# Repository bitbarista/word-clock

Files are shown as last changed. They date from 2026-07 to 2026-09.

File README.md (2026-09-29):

# TIME INVADERS — arcade word clock

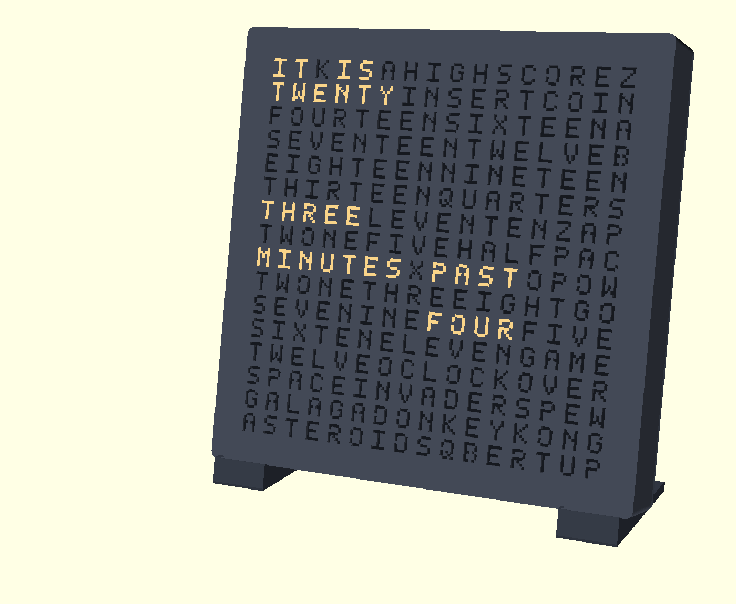
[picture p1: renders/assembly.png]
Assembled word clock on its desk feet showing IT IS TWENTY THREE MINUTES PAST FOUR


A 16×16 word clock with an 8-bit arcade heart: the time reads as words
to the exact minute (`IT IS TWENTY THREE MINUTES PAST FOUR`), but time
changes are game events — Pac-Man eats the old time, a cannon shoots
in the new one — and the filler letters hide arcade words
(INSERT COIN, GAME OVER, plus a hall of fame: SPACE INVADERS, GALAGA,
DONKEY KONG, ASTEROIDS, Q*BERT). The enclosure is deliberately subtle —
a plain dark slab that passes at a work desk, on raked feet or
wall-mounted; the arcade lives in the light, not the shell.

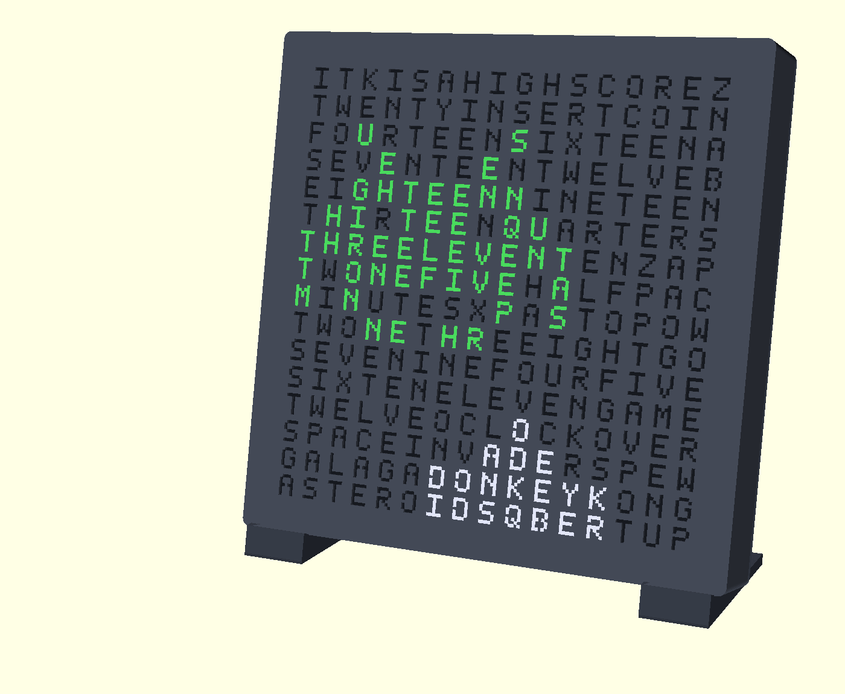
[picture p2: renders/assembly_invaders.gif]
The same clock playing the Space Invaders attract animation — an invader sprite marching over a cannon, drawn in lit letters


Every pixel is a letter: the attract-mode sprites are drawn by lighting
grid cells, like the invader marching over the cannon above.

**▶ [Try it in your browser](https://bitbarista.github.io/word-clock-demo/simulator.html)** —
live simulator running the real firmware logic: word grid, transitions,
attract mode, hidden words.

## What you need

| Item | Notes |
|---|---|
| 16×16 WS2812B flexible panel | 160×160 mm, 10 mm pitch — the common ~£12–15 one |
| Seeed XIAO ESP32S3 (or ESP32-S3 "supermini") | either fits the internal locator |
| Snap-in USB-C power socket, **4P PD pigtail** | CHT-TS023R style; 2P/data variants won't power from C-to-C cables |
| 5 V / 3 A USB-C supply | **must present 5 V** — verify with a meter before connecting the panel |
| 2× 5.1 kΩ resistors | CC1/CC2 → GND at the socket pigtail (skip if built in) |
| 1000 µF electrolytic (≥6.3 V) | across 5 V/GND at the panel pigtail |
| 330 Ω resistor | in the data line to DIN |
| Schottky diode (1N5817/19/22) | socket 5 V → ESP32 5 V pin |
| 3 mm foam sheet | cut into 14× 8×8 mm pads |
| 4× M3×**16** self-tapping screws | shell → faceplate posts (16 mm, not 8 — see [DESIGN.md](DESIGN.md)) |
| 74AHCT125 level shifter (optional) | only if 3.3 V data proves flaky |

## Print it

Sliceable files are committed — no OpenSCAD needed for a stock build:

- **[`build/desk_set.3mf`](build/desk_set.3mf)** — the desk build in
  one file: faceplate, shell, lattice, diffuser, and stand feet in
  both 12° and 15° tilt (print one pair).
- **[`build/wall_set.3mf`](build/wall_set.3mf)** — the wall build:
  keyhole hangers baked in, power socket on the bottom edge, no stand.
- [`build/`](build/) also has per-part STLs and exact STEP CAD exports
  ([`wordclock_assembly.step`](build/wordclock_assembly.step) is the
  full assembly) for other CAD tools.

Every part is a plain single-colour print: faceplate, shell, lattice
and stand in something dark; the diffuser in white or clear at 100 %
infill. Faceplate prints letters-down, shell outer-face-down,
everything else flat.

**Pick your diffuser first**: print `part="coupon"` (a four-cell
sample) plus `coupon_diffuser` strips at a few thicknesses (`t_diff` =
0.6 / 0.9 / 1.2, clear and white), try them over a lit LED, set
`t_diff` to the winner, then print the diffuser and lattice.

**Customising needs [OpenSCAD](https://openscad.org)** (free — open
`wordclock.scad`, use the Customizer): the committed files cover the
two stock configurations, everything else is a parameter + re-export —
`mount_type` (desk/wall), `power_pos` (cable entry: back or bottom),
`keyhole` (wall hangers), `tilt` (stand angle 5–25°), `t_diff`, or the
letter grid itself. `./export.sh` regenerates STLs + 3MF sets,
`./export_step.sh` the STEP files.

## Wire it

Four connections plus the supply handshake — see the schematic for the
full picture:

- Socket **V+/V− → panel 5 V/GND direct** (panel current never touches
  the ESP32), with the **1000 µF cap** across 5 V/GND at the panel
  pigtail.
- Socket 5 V **→ D1 (Schottky, cathode toward ESP32) → ESP32 5 V pin**;
  grounds common.
- ESP32 **GPIO4 → 330 Ω → panel DIN**.
- **CC1/CC2 → 5.1 kΩ → GND** (one each) at the socket pigtail, unless
  the socket has them built in.

Firmware enforces a per-frame power cap
(`FastLED.setMaxPowerInVoltsAndMilliamps(5, 2500)`) so no animation
can exceed the supply — don't remove it. Power-safety details and why
each part is there: [DESIGN.md](DESIGN.md).

<details>
<summary>Full circuit schematic (ASCII)</summary>

```
+=========================================================================+
|                   TIME INVADERS -- Circuit Schematic                    |
+=========================================================================+

POWER

  USB-C Power Pod (snap-in, 4P fast-charge/PD pigtail)
  +-------------+
  |  V+         |----------------------------------------------- 5V RAIL
  |  V-         |----------------------------------------------- GND RAIL
  |  CC1        |--[ R1 5.1k ]--+
  |  CC2        |--[ R2 5.1k ]--+-------------------------------- GND RAIL
  +-------------+

  R1/R2 request 5V/3A from the supply. Omit them if the socket
  already has CC resistors built in (only V+/V- emerge in that case).

  ESP32-S3 SuperMini
  5V RAIL  --[ D1 ]------------------------------------------------ 5V pin
  GND RAIL ------------------------------------------------------ GND pin

  D1: pod 5V -> ESP32 5V pin, cathode (banded end) toward the ESP32.
  Reinstates the isolation the XIAO's own USB port likely lacks (see
  note below) -- without it, don't power from the pod and a flashing
  cable at once.

  On hand: 1N5817 -- genuine Schottky (same 1N581x family as the
  1N5822/1N5819 the BOM recommends), 20V/1A, VF ~0.2-0.45V. Only
  difference from the BOM pick is current rating (1A vs 3A), which is
  fine here: D1 only carries the ESP32's own draw, not the panel
  (panel is fed V+/V- direct, bypassing D1) -- 1A comfortably covers
  the XIAO even during WiFi TX current spikes.

  ESP32-S3's OWN programming USB-C (internal cradle -- the only
  proven way to flash; web OTA is unproven, see Assemble it)

    USB-C connector
     VBUS ----------[ onboard Schottky ]---------------------- 5V RAIL
     GND  ------------------------------------------------------ GND RAIL

  This diode blocks GND RAIL -> VBUS backfeed, but NOT the reverse:
  if a laptop's VBUS sits above the pod's output, the laptop can end
  up sourcing panel current through this small onboard diode. The
  firmware's USB power guard detects a host on this port (via USB
  enumeration) and automatically clamps LED current to a safe budget
  while it's connected -- no extra wiring, but don't rely on the
  diode alone.

LED PANEL (16x16 WS2812B, 160x160mm, 256 LEDs)

  5V RAIL  --+----------------------------------------------------- Panel VCC
             |
         [ C1 1000uF ]
             |
  GND RAIL --+----------------------------------------------------- Panel GND

  ESP32-S3                                            Panel
  GPIO4 -----[ R3 330R ]----------------------------- DIN

  GPIO4 is a build flag (LED_PIN in platformio.ini) -- change there,
  not here, if your wiring differs. Optional: insert a 74AHCT125
  level shifter between R3 and DIN if 3.3V data proves unreliable
  driving the panel from 5V.

All GND labels share a common ground.
All 5V RAIL labels are the same net: fed primarily by the power pod
(V+/V- direct, no diode), and -- only while a host is enumerated on
the programming port -- additionally by that port's VBUS through the
onboard diode (current-limited in firmware when this happens).
```

</details>

## Assemble it

1. **Flash the ESP32 first** — over USB on the bench. The firmware has
   a web OTA endpoint, but it is **unproven**: its only real-world use
   sent a build that turned out to be broken, so OTA itself was never
   confirmed working. There's no external port on the finished clock,
   so recovering from a bad update means opening the case to reach the
   ESP32's USB-C. Until OTA is proven on a bench unit, plan to update
   over USB with the case open.
2. Faceplate letters-down on the desk → diffuser sheet into the
   opening → lattice on top of it → panel, **wire-exit edge toward the
   bottom** (shortest runs to the ESP32 and socket; firmware's mapping
   settings absorb whatever rotation this gives).
3. Foam pads on the 14 grid points; wiring lies in the open cavity
   between them.
4. Shell — with ESP32 (USB-C connector toward the locator's open end),
   power socket, and wiring attached — then four M3×16 screws.

First power-on: run a test pattern, set the panel mapping
(rotate/flip/serpentine) in the web UI, then leave it on attract mode
for a few hours and check nothing runs more than warm (the vent sizing
is calculated but not yet soak-validated — see [DESIGN.md](DESIGN.md)).

## Firmware

Lives on the [`firmware` branch](../../tree/firmware) (PlatformIO,
ESP32-S3). NTP + web UI — animation pick/interval, colours, brightness
schedule, timezone, panel mapping — with transition animations
(Pac-Man eat, cannon shoot-up, Tetris drop, invader zap), attract mode and
hidden-word easter eggs. Works fully offline too: it hosts its own
hotspot and can take the time from your phone with one tap
([DESIGN.md](DESIGN.md) has the details).

## The letter grid

```
IT K IS A HIGHSCORE Z         rows 0-8: minute words
TWENTY INSERTCOIN             rows 9-12: hour words + OCLOCK
FOURTEEN SIXTEEN A            rows 13-15: arcade hall of fame
SEVENTEEN TWELVE B
EIGHTEEN NINETEEN             hidden arcade words:
THIRTEEN QUARTER S            HIGH SCORE, INSERT COIN,
THREELEVEN TEN ZAP            ZAP/PAC/POW (stacked), GO,
TWONE FIVE HALF PAC           GAME/OVER (stacked),
MINUTES X PASTO POW           SPACE INVADERS, PEW, GALAGA,
TWONE THREEIGHT GO            DONKEY KONG, ASTEROIDS, QBERT, UP
SEVENINE FOUR FIVE
SIX TEN ELEVEN GAME
TWELVE OCLOCK OVER
SPACEINVADERS PEW
GALAGA DONKEYKONG
ASTEROIDS QBERT UP
```

Words share letters to fit per-minute wording into 16×16 (TWONE =
TWO+ONE, PASTO = PAST+TO, …) — the full construction is in
[DESIGN.md](DESIGN.md).

## More detail

- **[DESIGN.md](DESIGN.md)** — design notes and rationale: power
  budget, enclosure stack, ventilation, diffuser experiment, offline
  timekeeping, full BOM component notes.
- **[DEVLOG.md](DEVLOG.md)** — the engineering history: every bug,
  root cause, fix, and how each was verified.
- **[Concept comparison](https://bitbarista.github.io/word-clock-demo/wordclock-concepts.html)** —
  the enclosure concepts considered (arcade cabinet vs. subtle wedge);
  both demo pages are archived in [`docs/`](docs/) and mirrored to
  [word-clock-demo](https://github.com/bitbarista/word-clock-demo) for
  GitHub Pages hosting.

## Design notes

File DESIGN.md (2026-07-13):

# Design notes — TIME INVADERS word clock

[README.md](README.md) is the build guide; this file holds the design
rationale and current-state detail behind it. [DEVLOG.md](DEVLOG.md)
has the engineering history of how it all got this way.

## Project status

**v0.1.6 — model validated (manifold + collision-checked).**
Faceplate, shell, and stand have all been printed and iterated on
previous revisions, but v0.1.6 changed the depth budget, the
bezel/pocket wall, the power socket mount, and (to actually fit the
thicker slab) the stand's own wedge geometry (see [DEVLOG.md](DEVLOG.md)) —
**reprint the faceplate, shell, and stand** before assembling against
this revision; the old stand's slot was cut for the pre-v0.1.6 slab
thickness and won't fit. Firmware exists on the `firmware` branch (fw
v0.3.0, not yet merged to `main`), not started from scratch.

(The solid `stand` wedge and its `stand_sheet` variant discussed in
the devlog were superseded by `stand_feet`/`stand_lowtail`; the
groove/tilt/vent-relief profile work described there carried over
into both current stands.)

## Component notes (full BOM detail)

- **Seeed XIAO ESP32S3 or a generic ESP32-S3 "supermini"** — WiFi NTP
  + web UI + animations. Originally XIAO-only after none of three
  boards (two supermini vendors + the XIAO) fit an earlier snug
  cradle — since resolved (v0.1.4): the cradle is now a universal
  locator (`brd_w`/`brd_l`) sized to fit either, single end-stop only
  (see ESP32 access below).
- **Snap-in USB-C power socket, 4P PD pigtail** — CHT-TS023R style,
  5 A; 2P variant won't work with C-to-C cables. Mounts directly into
  the shell now, no separate pod part or screws (see Power budget &
  protection below).
- **1000 µF electrolytic (≥6.3 V)** — across 5 V/GND at the panel
  pigtail. **Check the physical size**: standard 1000µF caps run
  8–10mm diameter × 11.5mm+ tall (leaded or SMD, height doesn't change
  with package) — this needs the deepened back cavity (v0.1.6, see
  Enclosure stack below), it did not fit the original 3mm gap.
- **3 mm foam sheet, cut into 14× 8×8 mm pads (not a full sheet)** —
  behind the panel, pressed by the shell's pad grid — see Ventilation
  below for why it's pads, not a sheet.
- **4× M3×16 self-tapping screws** — shell → faceplate corner posts.
  **Not M3×8** — the screw has to clear 6.4mm of shell material before
  reaching the post at all; M3×8 leaves just 1.6mm of thread
  engagement, M3×16 gives ~9.6mm.
- **Level shifter (optional)** — 3.3 V data usually drives WS2812B
  fine at 5 V; add 74AHCT125 if flaky.
- **Schottky diode, 1N5817 (on hand — 1N5822/1N5819 also fine)** —
  pod 5 V → ESP32 5 V pin, cathode toward the ESP32 — the XIAO likely
  has no onboard VBUS diode, so without this, don't plug in the pod
  and a flashing cable at the same time during any future case-open
  debugging session (routine use never exposes the port — see ESP32
  access below). Must be Schottky (low forward drop): ordinary
  rectifiers (1N4007/5399/5408) work but sag the ESP32's 5 V more
  under WiFi TX current spikes; fast-recovery types (FR107/FR207) and
  small-signal diodes (1N4148) are unsuitable here. 1N5817 is only
  1 A vs the others' 3 A, but D1 carries just the ESP32's own draw
  (panel is fed direct, bypassing D1), so that's plenty of margin.

## Printed parts reference

Every part is a plain single-colour print — no filament swaps.

| Part | File | Orientation | Colour |
|---|---|---|---|
| Faceplate (stencil + tray) | `part="faceplate"` | letters on the bed | dark |
| Baffle lattice (drop-in) | `part="lattice"` | flat on bed | dark |
| Diffuser sheet (drop-in) | `part="diffuser"` | flat on bed, 100 % infill | white or clear — experiment |
| Rear shell (incl. power socket mount) | `part="shell"` | outer face on bed | dark |
| Desk stand — pair of feet (current default; `tilt` 12°, a 15° variant is also exported) | `part="stand_feet"` | flat base on bed | dark |
| Desk stand — full-width low-tail wedge (alternative to the feet) | `part="stand_lowtail"` | flat base on bed | dark |
| Test coupon | `part="coupon"` | letters on bed | dark |
| Coupon diffuser strips | `part="coupon_diffuser"` | flat, 100 % infill | one per candidate |
| Power socket coupon | `part="pod_coupon"` | flange face on bed | any — test print, not visible |

The 3MF sets contain each part as an individually selectable object.
The STEP exports are exact BRep (analytic cylinders/planes), with
`wordclock_assembly.step` carrying faceplate/shell/stand feet as named
solids in their assembled positions; regenerating them
(`./export_step.sh`) needs FreeCAD — see `step_export/`.

## ESP32 access — flash once, then OTA

The ESP32 sits in an internal locator cradle above the power socket
(`esp_x`/`esp_y`) — there is no external USB port. The locator has a
universal footprint (`brd_w`/`brd_l`) that fits both the Seeed XIAO
ESP32S3 and generic ESP32-S3 "supermini" boards, registering either
against a single end-stop wall (`esp_stop_t`); retention is the
soldered leads plus the shell closing over everything.

**Flash once over USB on the bench before final assembly, then update
OTA over WiFi.** When inserting the board, point its USB-C connector
at the open end of the locator (away from the end-stop wall) — the
geometry can't encode which end the connector is on. **Trade-off, gone
into with eyes open:** if OTA ever bricks, recovery means opening the
case (four corner screws) and re-flashing on the bench, not a quick
cable plug-in through the wall.

(The cradle went through five design revisions — corner brackets, a
clearance bug, the universal footprint, the end-stop — see
[DEVLOG.md](DEVLOG.md).)

## Power budget & protection

The numbers (WS2812B ≈ 60 mA/LED full white):

| Frame | @30 % brightness |
|---|---|
| Word display, worst wording (~32 cells white) | ~0.6 A |
| Full-face sprite (~130 cells, coloured) | ~1.2–2 A |
| All 256 white (the trap) | ~4.6 A |

A global brightness cap therefore does NOT guarantee a safe current
for arbitrary animation frames. Two-layer solution:

1. **Per-frame power limiting in firmware — mandatory.**
   `FastLED.setMaxPowerInVoltsAndMilliamps(5, 2500)` scales each
   frame so its computed power never exceeds the budget. Sparse word
   frames render at full set brightness; dense attract-mode frames
   dim themselves automatically. This is the guarantee — no animation
   we ever add can exceed the budget (and it doubles as brown-out
   protection for the shared 5 V rail).
2. **Separate power inlet — panel current never touches the dev
   board.** A panel-mount USB-C power socket (pigtail type) mounts
   bottom-middle, above the stand horn, invisible in use. **v0.1.6:
   mounts directly into the shell now** — no separate pod part, no
   screws. Used to be a bump-out part screwed on from the inside
   (meant removing it required separating the whole shell from the
   faceplate to reach those screws); now that the shell has real
   interior depth (see Enclosure stack), the socket's snap-fit flange
   passes through the shell's own material directly, retained purely
   by its own snap wings, same as before, just without the extra part.
   Its 5 V pigtail feeds the panel pigtail AND the ESP32 5 V pin
   directly; grounds common (wires just lie in the open cavity between
   the foam pads — see Ventilation, no channel-cutting needed). The
   ESP32's own USB-C — in an internal cradle above the pod, not a
   side-wall port (see ESP32 access) — is bench-flash-only pre-
   assembly, then OTA.

   **⚠ The XIAO ESP32S3 does not have the onboard VBUS Schottky diode
   that some "supermini" boards use to isolate their two USB/power
   inputs** (unconfirmed against Seeed's schematic, but assume not
   present). Without D1, the ESP32's own USB-C and the pod's 5 V feed
   are directly tied together on the same rail with nothing stopping
   the pod's 5 V from backfeeding into a laptop's USB port if both are
   connected at once.

   This isn't really an *accidental*-connection risk anymore — the
   port is buried in an internal cradle, so reaching it at all means
   deliberately opening the case, which never happens during normal
   use. But that's exactly the situation where it stays relevant:
   **future firmware debugging** (serial monitoring, re-flashing)
   naturally wants the panel running normally off the pod *while* a
   laptop is also connected to the now-exposed port — same backfeed
   hazard, just reached through a deliberate step instead of an
   accidental one. D1 is a $0.20 part already on hand and already in
   the schematic, so there's no reason to remove it on the strength of
   routine access going away — **don't plug both in at the same time
   during any future case-open debugging session** unless D1 is fitted
   (it should be — see the schematic in the README). Different failure
   mode than the firmware USB-power-guard in `usbguard.h`, which only
   throttles the *other* direction (a host over-powering the panel)
   and can't protect a laptop from rail backfeed.

Socket: **snap-in pigtail USB-C female, 4P PD/fast-charge variant**.
Mounting cutout: **14.7 × 5.4 mm R1.3** (measured off the actual
delivered part, long side trimmed 0.3 mm after a test fit — supersedes
the earlier CHT-TS023R drawing estimate). The socket snaps directly
into the shell's own `lid_t` (2.4mm) now — the verified-working figure
from the old separate-pod part was 2.0mm exactly, so this is 0.4mm
thicker than what was actually tested; worth confirming the snap
wings still engage properly on the physical part rather than assuming
(`part="pod_coupon"` is a small standalone test piece of exactly this
local geometry — print it and check the real socket snaps in before
committing to a full shell print). Cavity behind it for body + wing
deployment is 8mm deep (that number was always fine — see
[DEVLOG.md](DEVLOG.md) for what actually needed fixing).

- **Buy the 4P fast-charge/PD pinout (V+, V−, CC1, CC2) — not the
  2P, and not the 4P "data" pinout (D+/D−).** Without CC pins a
  compliant USB-C supply never enables VBUS on a C-to-C cable.
- The CC wires connect to **nothing downstream** — their only job is
  the supply handshake. Solder **5.1 kΩ from CC1 to GND and 5.1 kΩ
  from CC2 to GND** (one each, not shared) right at the pigtail,
  heat-shrink, tuck away. This requests 5 V/3 A. If the delivered
  socket has the resistors built in (listing says "with CC resistor",
  or only V+/V− emerge), skip this — VBUS and GND are then the only
  connections.
- **It must present 5 V.** These passthrough sockets don't negotiate
  voltage themselves, but verify with a multimeter before first
  connection to the panel — 9/12/20 V kills WS2812s instantly.
- Socket mount dimensions (`pwr_snap_w/h/r`, `pwr_cavity`) are
  Customizer parameters — adjust them if a future socket differs.

Supporting cast, standard WS2812 practice: **1000 µF electrolytic**
across 5 V/GND at the panel pigtail (also stops the ESP32 browning
out on frame spikes — it shares the rail), **330 Ω** in the data line,
short 20 AWG power wires. Data from a GPIO to DIN, short lead.

The back panel is deliberately clean; if you ever outgrow USB-C power
entirely, add a cable exit in `shell()` and feed the pigtail from a
dedicated 5 V PSU.

## The face stack & the diffuser experiment

The faceplate is a 1.2 mm dark stencil (letters are through-voids)
with the bezel ring and tray behind it. The **diffuser is a separate
sheet** that drops into the opening against the stencil's back, and
the **lattice drops in after it**, pressing it flat; the panel, foam
and shell clamp the whole stack. The diffuser is therefore swappable
forever — four shell screws.

Finding the right diffuser is the point of the **coupon**: a 48 mm
four-cell sample with a slide-in slot along one edge. Print
`coupon_diffuser` strips at several thicknesses (set `t_diff` to 0.6 /
0.9 / 1.2) in clear and white, slide each into the slot over a lit
LED ~12 mm behind, and judge hotspots and glow. Clear PETG frosts
usefully at 4–6 layers; white diffuses more per layer but costs
brightness. When you've picked, set `t_diff` to the winner and print
the full-size `diffuser` — the lattice depth derives from `t_diff`,
so print the lattice after the decision.

The font is a purpose-made 5×7 pixel stencil face (`font.scad`):
letters with enclosed counters (A B D O P Q R) carry a bridge, so the
stencil plate is self-supporting and nothing floats on the bed.

## The letter grid — how it fits

QBERT, not Q*BERT — the arcade game's actual title has an asterisk
(`font.scad` has no glyph for one, so the grid spells it without).
Kept as "Q*BERT" in prose elsewhere since that's the real name; only
the on-grid spelling drops the asterisk.

Per-minute wording fits 16×16 through letter-sharing: FOURTEEN,
SIXTEEN, SEVENTEEN, EIGHTEEN, NINETEEN carry FOUR, SIX, SEVEN, EIGHT,
NINE as prefixes; TWONE = TWO+ONE, THREELEVEN = THREE+ELEVEN,
THREEIGHT = THREE+EIGHT, SEVENINE = SEVEN+NINE, PASTO = PAST+TO, and
MINUTE is a prefix of MINUTES. Grammar: `ONE MINUTE`, `A QUARTER` /
`HALF` (no MINUTES), 21–29 = TWENTY + unit, and past 30 minutes it
counts down TO the next hour. The X in row 8 is a deliberate spacer:
MINUTES PAST is lit 48 minutes of every hour, so it earns a gap
(TWELVE OCLOCK stays adjacent — it shows for one minute twice a day).
The stand's front lip is deliberately low (13 mm) so the bottom
hall-of-fame row stays visible above it.

Since words change every minute, firmware runs the big game
transitions on 5-minute boundaries (configurable) and a quick
crossfade on ordinary minute ticks — Pac-Man every 60 s would wear
thin fast.

## Enclosure stack (front → back)

1.2 stencil plate → drop-in diffuser sheet (t_diff) → drop-in baffle
lattice (1.2 mm walls landing between LEDs, depth = 12 − t_diff) →
panel (2.0) → back cavity (13.0, houses foam pads + all electronics)
→ shell's pad grid presses the whole stack against the stencil. Shell
lip registers inside the tray wall, four M3×16 self-tappers into the
corner posts. Power enters via a socket mounted directly into the
shell; the ESP32 sits in an internal locator above it, flashed via
USB on the bench pre-assembly and OTA thereafter (see ESP32 access).

Face is 184×184 mm, slab **31 mm** thick (was 21mm — see the v0.1.6
depth-budget audit in [DEVLOG.md](DEVLOG.md)), 12° rake in the stand.

## Panel orientation

**Wire-exit edge toward the bottom** (the same edge the power pod and
ESP32 sit near). The panel used here has three separate connector
clusters along one edge (5V/GND/DIN, a mid-panel power-injection tap,
5V/GND/DOUT — not a single corner pigtail), so orientation actually
matters: bottom gives the shortest wire runs (60mm to the ESP32, 36mm
to the pod, vs. 140mm+ from the opposite edge) and every connector
clears the pad grid by 17mm or more. Firmware corrects whatever
reading rotation this produces — `cellToLed()` (`display.cpp`) fully
implements `mapRotate`/`mapFlip`/`mapSerp` — dial that in empirically
at first power-on (run a test pattern, see which corner lights first,
adjust in the web UI) rather than something computable in advance
without knowing this specific panel's default LED index origin.

## Ventilation

The clock runs 24/7, so the shell is built for passive cooling, not
sealed:

- **Pressure pads, not a foam sheet.** The panel is pressed flat by a
  sparse grid of 14 8×8 mm pads (a 3×3 inner grid minus the point that
  lands in the socket cavity, four corner pads, and two edge-midpoint
  pads). Every pad lands on an exact lattice wall crossing — never on
  open cell area or behind an LED — and the 3 mm foam (BOM) is cut
  into matching squares, so most of the panel's back face is open air
  instead of insulated.
- **Vent slots through the lid.** Two rows of 18 slots each, 3×25 mm,
  at the device's top and bottom edges for a passive chimney effect
  (the stand rakes the face at a real angle: cool air in low, warm air
  out high, no fan). Sized by natural-convection stack-effect scaling
  for 10 W sustained load at ΔT=35 °C (~1315 mm² per row), not guessed.

**Not yet thermally validated** — the collision checks and the sizing
calc are both just paper (well, CAD). Soak-test after printing
(attract mode, few hours, ambient desk conditions, check the panel/
ESP32 aren't running hot to the touch) before trusting this unattended
long-term; `vent_slot_n`/`vent_span` are easy to bump further if it's
still running warm.

The full sizing derivation and the design history (why pads, the
corner/edge-pad additions, the vent-count resize) are in
[DEVLOG.md](DEVLOG.md).

## Firmware notes

Beyond the README summary: a wandering-Pac ambient mode; hidden-word
easter eggs (the full 9-word list is on the grid — see README), each
firing on its own `wordsMin`/`attractMin` timer, default 10/30
minutes, adjustable in the web UI. MQTT/Home Assistant notification
words are a possible v2. The
[simulator](https://bitbarista.github.io/word-clock-demo/simulator.html)
is the behavioural spec — the grid, word logic and animations there
are what the firmware does.

## Running without internet (e.g. a work desk that can't join company WiFi)

No live internet connection is required for the clock to function.
WiFi is attempted once at boot (15s timeout, using whichever
credentials were last saved via the web UI); if that fails, it falls
back to hosting its **own access point** (`TIME-INVADERS`, password
`insertcoin`) and keeps running regardless, displaying whatever time
it currently has — it doesn't block on or require a connection to
work.

**Manual time sync needs no internet on either end.** The web UI has
a **"⏆ Sync time from this device"** button that POSTs the connected
phone/laptop's own clock straight to the word clock (`/api/time`).
Connect your phone or laptop to the clock's own `TIME-INVADERS`
hotspot, open its web UI, tap the button — no company WiFi, no
personal hotspot's internet, no NTP involved at all, just a direct
local connection to the clock itself. This is the practical option
when company WiFi isn't permitted and a personal hotspot won't be on
permanently: a quick visit to the clock's own hotspot, whatever
interval suits you, substitutes for NTP.

**Between syncs, accuracy depends on the ESP32-S3's own crystal** —
there's no battery-backed RTC chip in the BOM (e.g. a DS3231), so
timekeeping between syncs will drift at whatever rate the onboard
crystal happens to (typically low single digits of seconds/day, not
a guaranteed spec, and heat from nearby LEDs won't help). For a clock
that displays the exact minute, that's a real, visible effect over
days-to-weeks without a resync, not just theoretical.

**Power loss is handled as continuity, not correction.** The current
time is checkpointed to flash every 5 minutes, so a power cycle
without WiFi resumes from roughly where it left off rather than
resetting to zero — but whatever drift had already accumulated
carries through unchanged.

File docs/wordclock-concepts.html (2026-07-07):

Concept render · 16×16 WS2812 · ESP32-S3

# One clock, two shells

Both faces below are the same grid, same firmware, live right now — they're showing your actual local time using the real word-clock logic, and the demo buttons run the actual animation concepts. The only differences between the two concepts are the enclosure and how loudly the filler letters announce themselves.

Animations run on both faces at once so you can compare how each shell carries them. On the real clock these fire automatically on time changes, on an idle timer, or from the web UI.

▶ Pac-Man eats the time ▶ Matrix rain ▶ Invader attract mode ▶ Ghost attract mode ▶ Reveal hidden words wandering Pac-Man

## A — Full arcade

TIME INVADERS

© 1982 BITBARISTA

INSERT COIN

- Mini-cabinet stand: marquee, T-moulding stripes, control panel, coin legend.
- Livery comes from separate single-colour printed parts, not multi-colour printing.
- Filler letters are deliberately arcade words — invisible until an animation lights them.

## B — Subtle

- Plain 12° wedge in one dark colour; reads as a modern desk object.
- Identical animations — the arcade lives entirely in the light, not the shell.
- Same hidden-word grid (or random filler if you'd rather keep it straight).

### Reading the face

The clock reads the exact minute in words — IT IS TWENTY THREE MINUTES PAST FOUR. What makes per-minute wording fit a 16×16 grid is letter-sharing: FOURTEEN carries FOUR inside it, SEVENTEEN carries SEVEN, TWONE is TWO and ONE, THREELEVEN is THREE and ELEVEN, and PASTO is PAST and TO. Because the letters are a fixed stencil, the Matrix rain has a lovely property: the "falling glyphs" are the real letters of the face, and the rain literally resolves into the time.

### The livery question

You don't need a multi-colour printer for the cabinet look. The face plate uses your layer-swap trick (dark → white diffuser → dark, letters as voids in a pixel stencil font). The cabinet livery is achieved by printing the shell as separate parts in different filament colours — black body, amber marquee surround, red/yellow T-moulding strips that snap into grooves — which is exactly how real cabinets are built, and single-colour parts assembled always look cleaner than colour changes mid-part. The marquee text itself can be a second stencil with an LED behind it.

The decision: shell A or shell B — everything on the screen is common to both. There's also a middle path: the subtle wedge with a snap-on marquee, so the cabinet is optional dress-up.

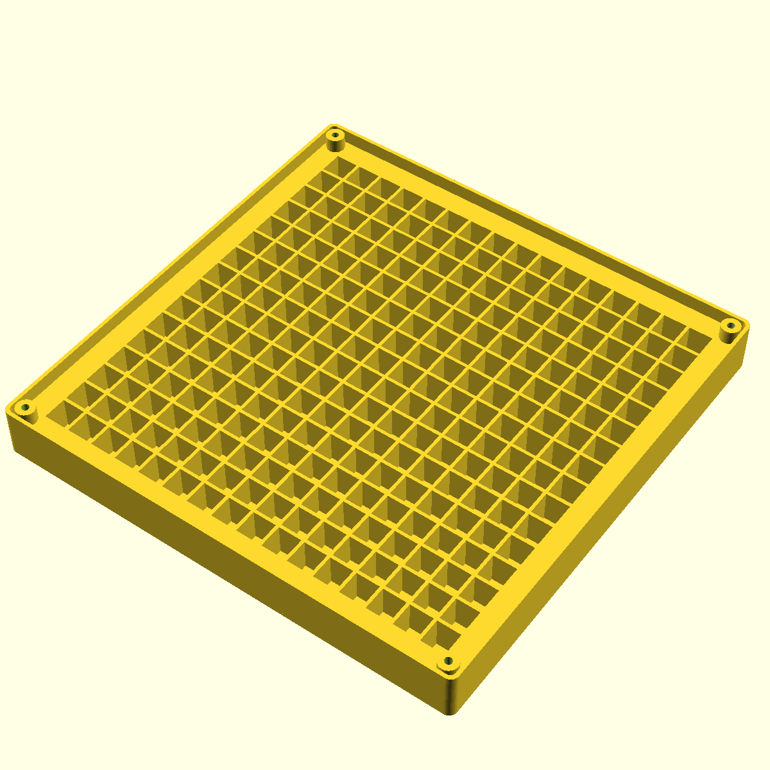
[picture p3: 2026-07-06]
renders/faceplate_back.png

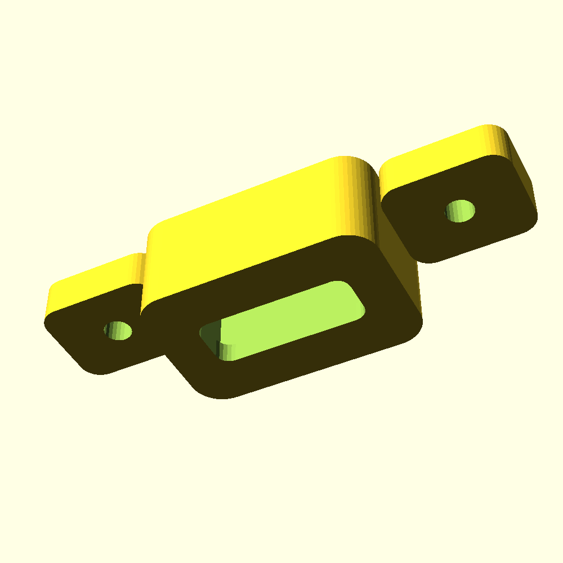
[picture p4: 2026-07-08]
renders/pod_face.png

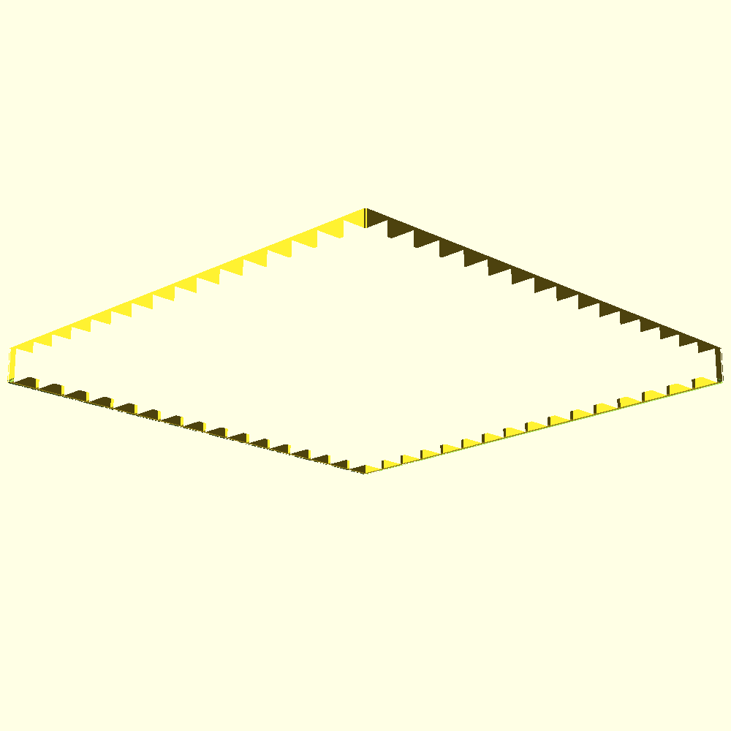
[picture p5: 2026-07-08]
renders/lattice_corner.png

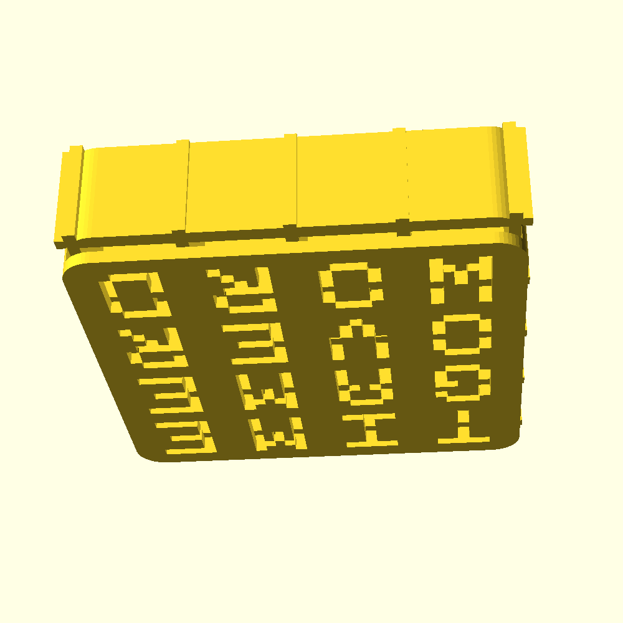
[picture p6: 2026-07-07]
renders/coupon_slot.png

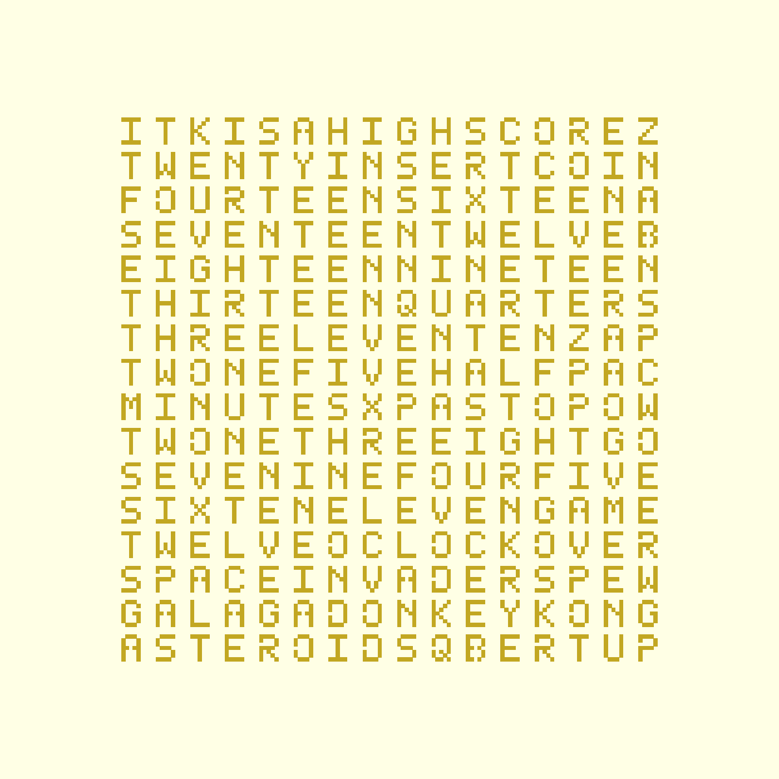
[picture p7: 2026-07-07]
renders/face2d.png

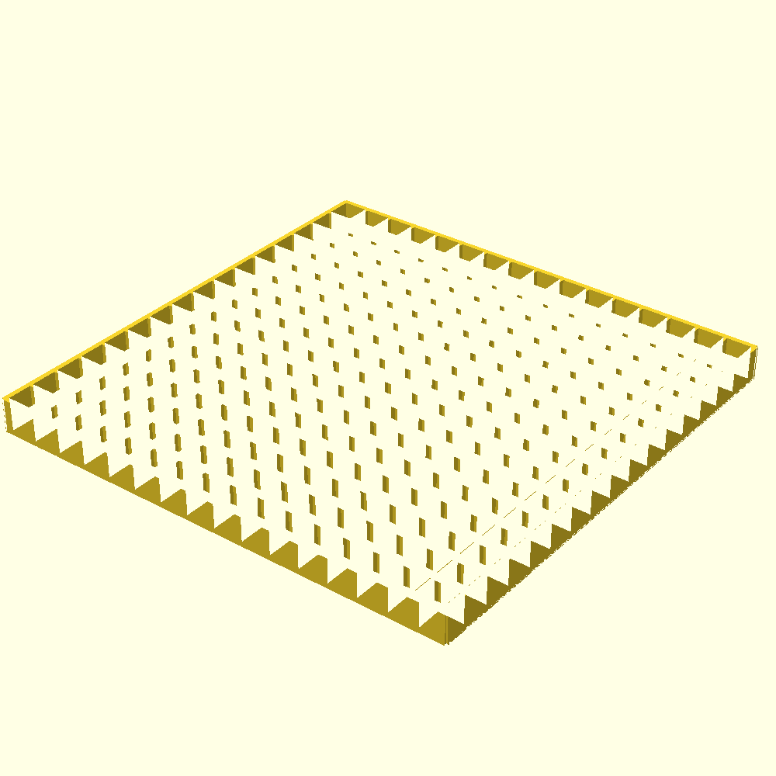
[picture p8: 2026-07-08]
renders/lattice.png

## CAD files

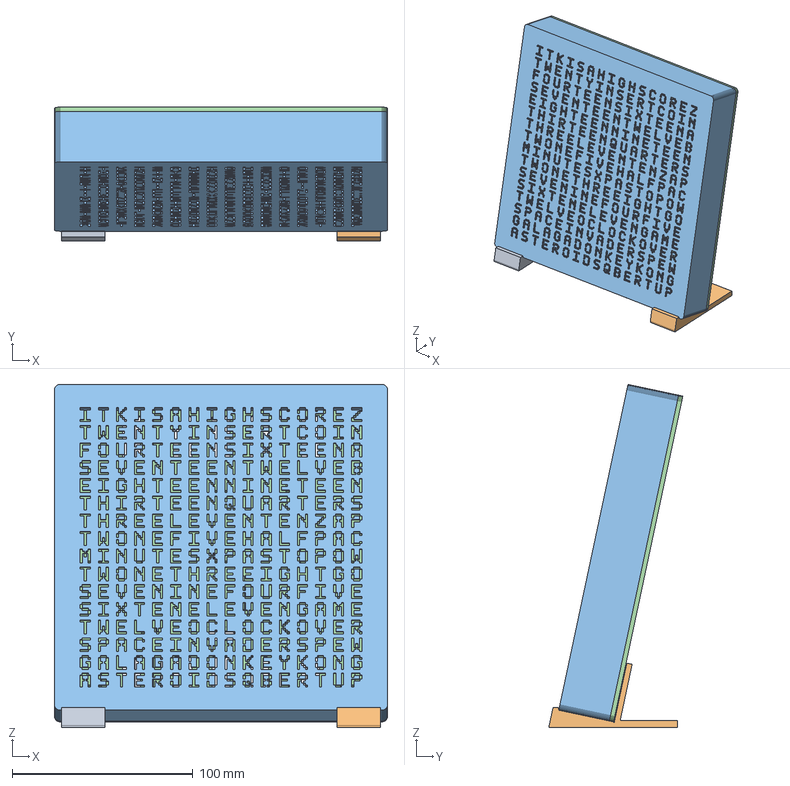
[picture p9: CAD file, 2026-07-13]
build/wordclock_assembly.step
184.0 x 73.9 x 189.6 mm
stand_feet
faceplate

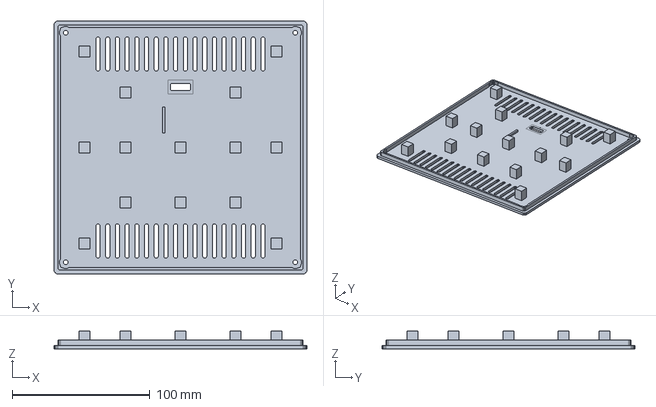
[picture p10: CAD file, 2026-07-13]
build/shell.step
184.0 x 184.0 x 12.9 mm

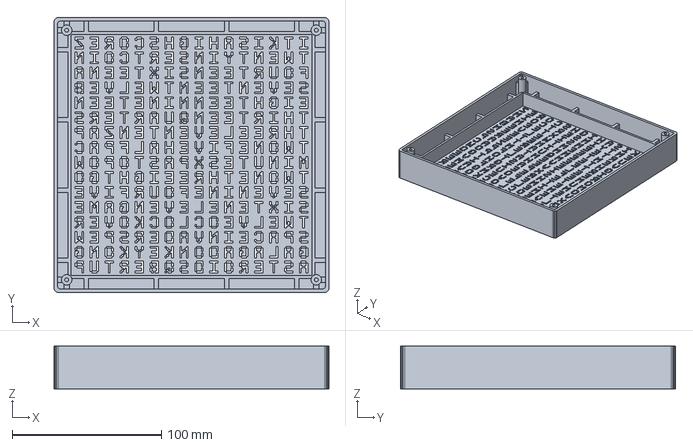
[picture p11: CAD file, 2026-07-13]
build/faceplate.step
184.0 x 184.0 x 28.6 mm

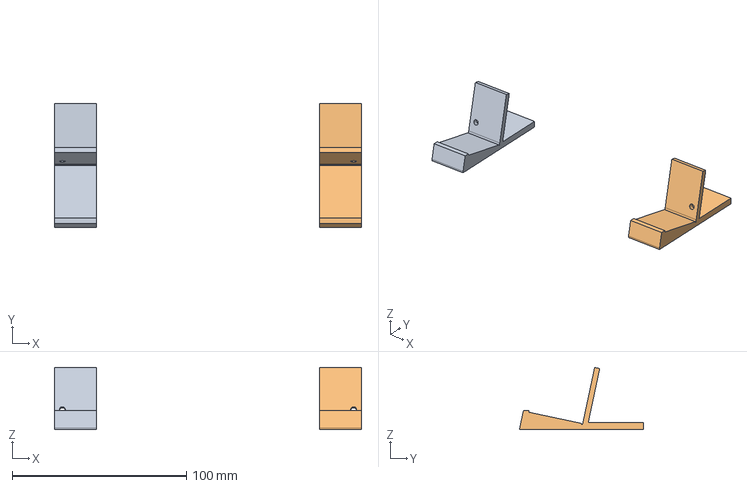
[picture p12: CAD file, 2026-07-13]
build/stand_feet.step
176.0 x 70.8 x 35.6 mm

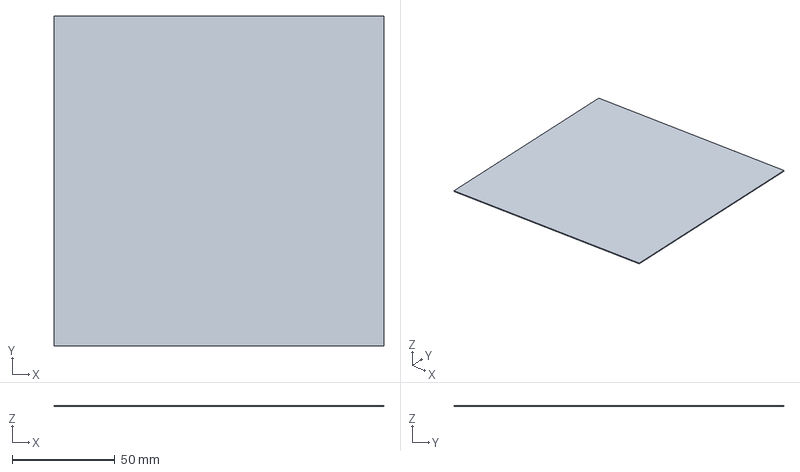
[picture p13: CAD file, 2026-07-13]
build/diffuser.step
160.2 x 160.2 x 0.6 mm

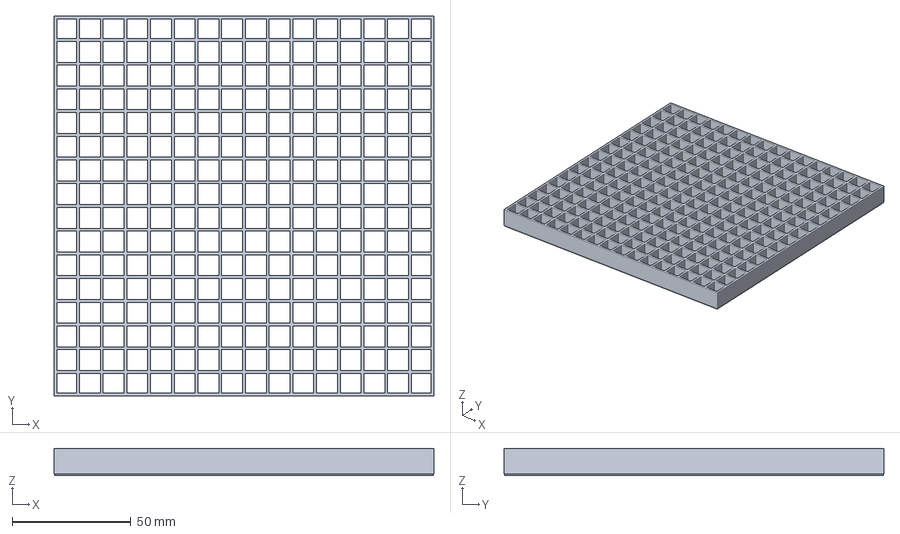
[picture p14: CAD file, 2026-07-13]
build/lattice.step
160.2 x 160.2 x 11.4 mm

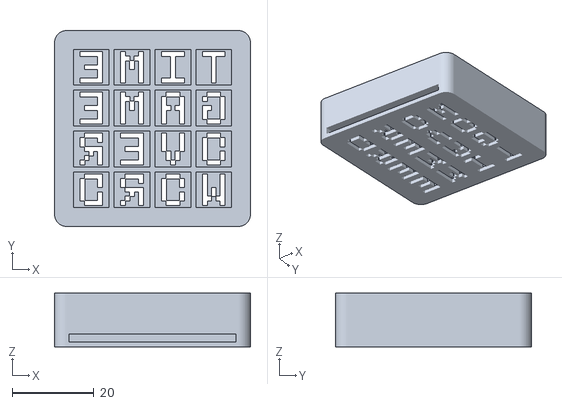
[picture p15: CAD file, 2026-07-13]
build/coupon.stl
48.0 x 48.0 x 13.2

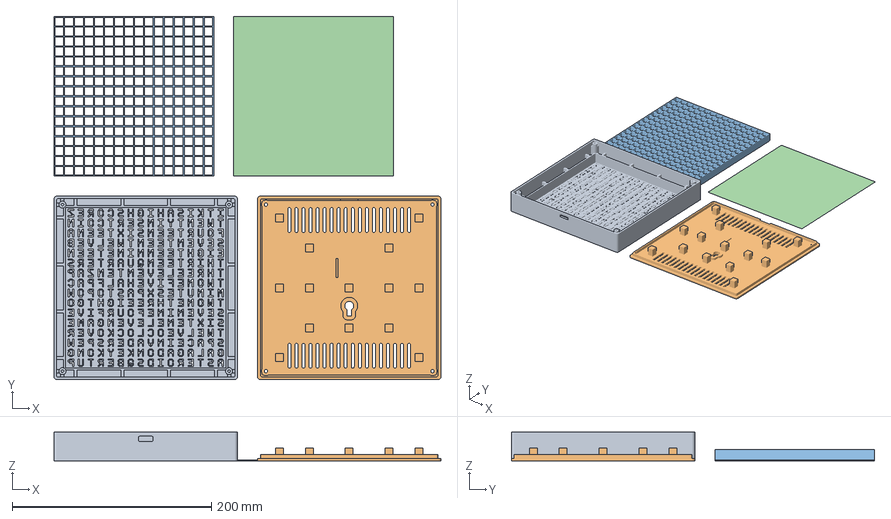
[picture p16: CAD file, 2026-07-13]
build/wall_set.3mf
388.0 x 364.2 x 28.6 mm
faceplate
lattice
diffuser

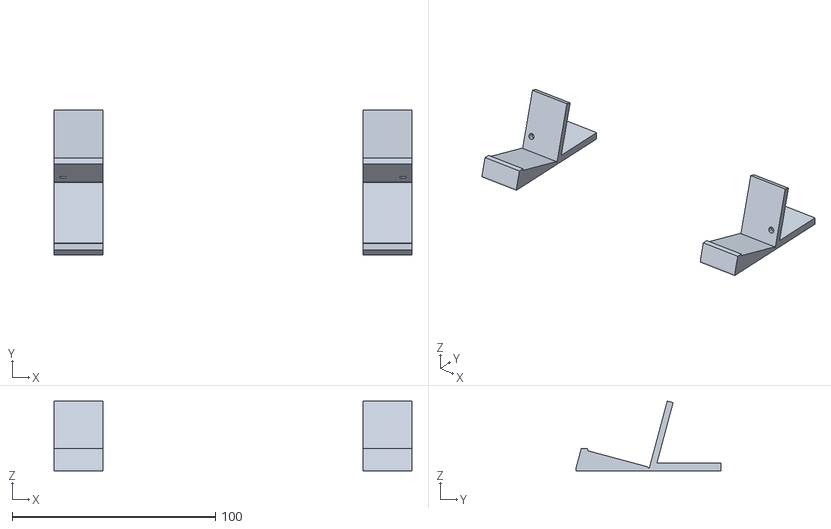
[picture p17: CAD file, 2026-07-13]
build/stand_feet_tilt15.stl
176.0 x 71.5 x 34.4

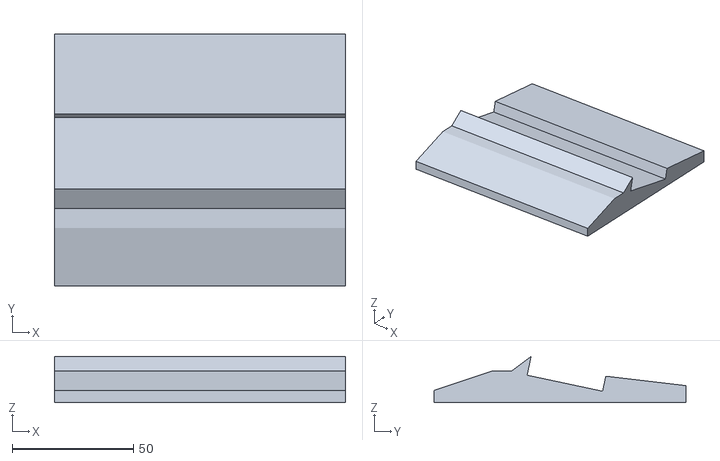
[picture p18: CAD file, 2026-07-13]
build/stand_lowtail.stl
120.0 x 104.0 x 19.1

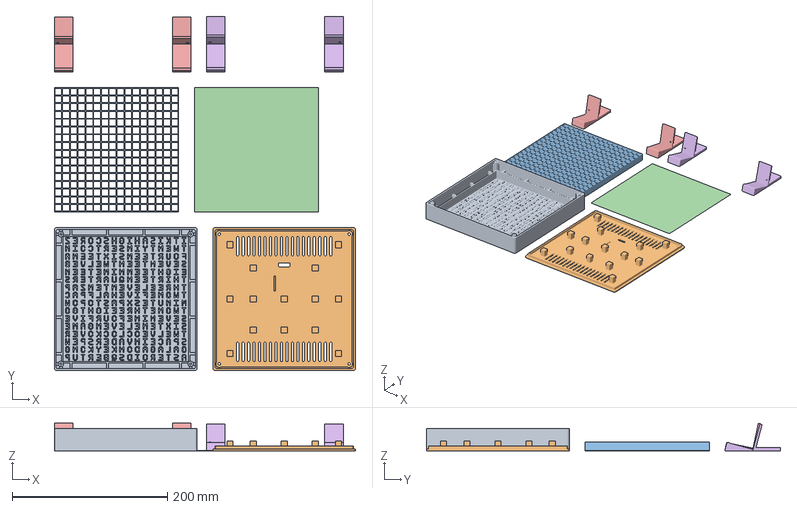
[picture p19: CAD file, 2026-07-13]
build/desk_set.3mf
388.0 x 455.7 x 35.6 mm
faceplate
lattice
diffuser
stand_feet_12deg
stand_feet_15deg

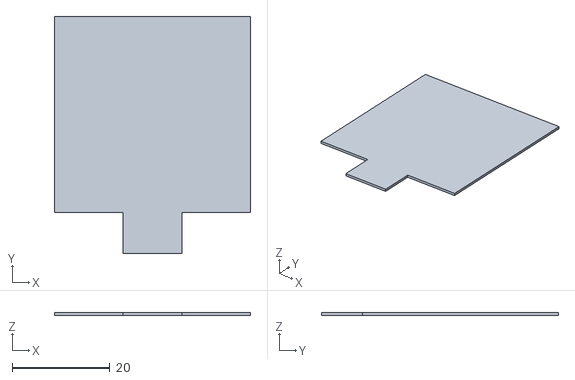
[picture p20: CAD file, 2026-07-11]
build/coupon_diffuser.stl
40.2 x 48.7 x 0.6

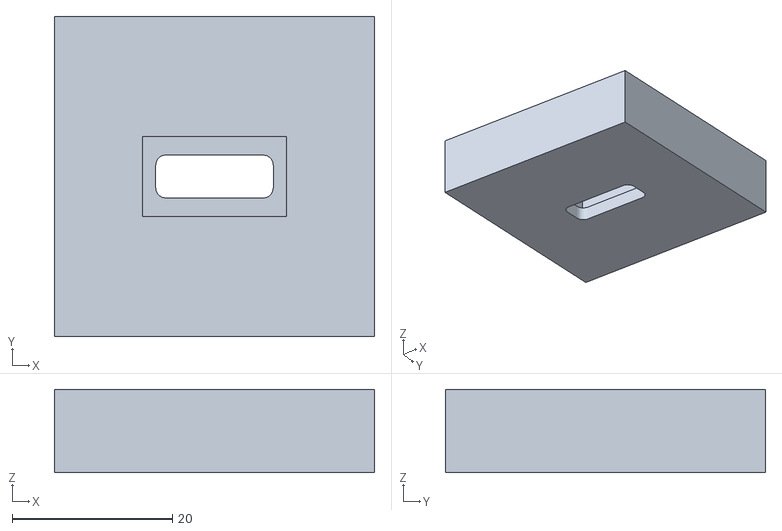
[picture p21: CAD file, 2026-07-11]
build/pod_coupon.stl
40.0 x 40.0 x 10.4

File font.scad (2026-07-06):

// ---------------------------------------------------------------
// 5x7 stencil pixel font for the word clock face
// "1" = void (light shines through), "0" = plate material.
// Letters with enclosed counters (A B D O P Q R) carry a stencil
// bridge so no island of face material floats unanchored on the
// bed when the plate prints letters-down.
// ---------------------------------------------------------------

FONT = [
["A",["01110","10001","10001","11011","10001","10001","10001"]],
["B",["11110","10001","10001","11010","10001","10001","11010"]],
["C",["01110","10001","10000","10000","10000","10001","01110"]],
["D",["11110","10001","10001","00001","10001","10001","11110"]],
["E",["11111","10000","10000","11110","10000","10000","11111"]],
["F",["11111","10000","10000","11110","10000","10000","10000"]],
["G",["01110","10001","10000","10011","10001","10001","01110"]],
["H",["10001","10001","10001","11111","10001","10001","10001"]],
["I",["11111","00100","00100","00100","00100","00100","11111"]],
["J",["00111","00010","00010","00010","00010","10010","01100"]],
["K",["10001","10010","10100","11000","10100","10010","10001"]],
["L",["10000","10000","10000","10000","10000","10000","11111"]],
["M",["10001","11011","10101","10101","10001","10001","10001"]],
["N",["10001","11001","10101","10011","10001","10001","10001"]],
["O",["01110","10001","10001","00001","10001","10001","01110"]],
["P",["11110","10001","00001","11110","10000","10000","10000"]],
["Q",["01110","10001","10001","00001","10101","10010","01101"]],
["R",["11110","10001","00001","11110","10100","10010","10001"]],
["S",["01111","10000","10000","01110","00001","00001","11110"]],
["T",["11111","00100","00100","00100","00100","00100","00100"]],
["U",["10001","10001","10001","10001","10001","10001","01110"]],
["V",["10001","10001","10001","10001","01010","01010","00100"]],
["W",["10001","10001","10001","10101","10101","11011","10001"]],
["X",["10001","10001","01010","00100","01010","10001","10001"]],
["Y",["10001","10001","01010","00100","00100","00100","00100"]],
["Z",["11111","00001","00010","00100","01000","10000","11111"]]
];

function glyph_row(ch, r) =
    let (hit = search([ch], FONT))
    (hit == [] || hit[0] == []) ? undef : FONT[hit[0]][1][r];

// One letter, centred on the origin. px = pixel size; bleed
// slightly oversizes each pixel so diagonal strokes (V X Z K...)
// overlap instead of touching corner-to-corner (manifold safety).
module glyph2d(ch, px = 1.1, bleed = 0.12) {
    if (ch != " " && glyph_row(ch, 0) != undef)
        for (r = [0:6], c = [0:4])
            if (glyph_row(ch, r)[c] == "1")
                translate([(c - 2) * px, (3 - r) * px])
                    square(px + bleed, center = true);
}

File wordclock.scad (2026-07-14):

// =================================================================
// TIME INVADERS — 16x16 word clock, subtle desk-wedge enclosure
// -----------------------------------------------------------------
// Shell concept "B — Subtle": plain slab in a raked desk stand.
// The face is a LAYERED STACK of single-colour prints (no filament
// swaps): dark stencil plate (letters are through-voids) → drop-in
// diffuser sheet (print several thicknesses/materials and A/B them)
// → drop-in baffle lattice → LED panel → foam → shell.
// Electronics: 16x16 WS2812B flexible panel (160x160, 10 mm pitch)
// + Seeed XIAO ESP32S3.  See README.md for the print/assembly guide.
// =================================================================

VERSION = "0.1.6";
echo(str("word clock model v", VERSION));

include <font.scad>

/* [Part] */
part = "assembly"; // [assembly, faceplate, lattice, diffuser, shell, stand_lowtail, stand_feet, coupon, coupon_diffuser, pod_coupon, face2d]
// assembly()'s real colours (see device()/assembly() near the bottom of
// this file) are a deliberately dark charcoal/near-black colourway,
// matching the actual enclosure — but that leaves almost no contrast
// in OpenSCAD's own preview, making edges and part boundaries hard to
// read while editing. Flip this off for a high-contrast preview
// palette instead. Print colour is actually arbitrary (whatever
// filament you choose) — true_colors=true (default) just previews a
// dark colourway as one example, not a manufacturing constraint.
true_colors = true; // [true, false]
// Light the face up in the assembly preview: "time" spells out
// IT IS TWENTY THREE MINUTES PAST FOUR (4:23 — shows off the
// per-minute wording), "invaders" shows a frame of the Space
// Invaders attract animation (sprites match the firmware's
// animations.cpp). Render/preview only — adds nothing to any
// printable part, and does nothing outside part="assembly".
face_display = "off"; // [off, time, invaders]

/* [Mounting] */
// Single switch for the two mounting styles — sets power_pos and
// keyhole together (see [Electronics] below) and drops the desk stand
// from the assembly() preview for "wall", so there's one place to look
// instead of hunting for the individual params. Still just a derived
// default: power_pos/keyhole are ordinary variables underneath, so
// advanced/mixed setups (e.g. bottom connector on a desk build) are
// still possible by editing them directly further down — this toggle
// just isn't exposed as a separate Customizer control for that case,
// since it's not the common path.
mount_type = "desk"; // [desk, wall]

/* [LED panel] */
// LED-to-LED spacing of the matrix panel
pitch = 10;
// LEDs per side
cells = 16;
// panel PCB + LED component height — measured (calipers): bare FPCB
// 0.25mm, 1.8mm total with LEDs mounted. 2.0mm modeled keeps a small
// margin over the measured 1.8mm.
panel_t = 2.0;
// Depth of the cavity behind the panel — houses the foam pressure
// pads, the ESP32 locator, the 1000uF cap, and (as of this revision)
// the power socket. Was 3.0mm ("foam_t"), sized only for a
// compressible foam sheet without ever checking it against the real
// components that have to physically live in it: the ESP32 (XIAO
// measured 4.49mm PCB-to-USB-C-top) and the 1000uF cap (11.5mm
// minimum, any standard package, leaded or SMD) both failed to fit —
// see README for the full audit. Resized to the tallest real
// component (the cap) plus margin, rather than patching each
// component separately or adding local bump-outs: a flat back was a
// deliberate requirement, so the extra depth goes into the whole
// device's thickness instead. 11.5mm + 1.5mm margin = 13mm.
back_t = 13.0;

/* [Face plate] */
// stencil plate thickness (letters are through-voids)
t_front = 1.2;
// diffuser sheet thickness — a SEPARATE drop-in part; print a few
// (0.6 / 0.9 / 1.2, clear vs white) and A/B them in the coupon slot
t_diff = 0.6;
// depth of the per-cell baffle lattice behind the diffuser
baffle_d = 12;
// baffle wall thickness (lands between LEDs)
lat_wall = 1.2;
// bezel width beyond the LED grid
bezel = 12;
// stack-pocket wall: hollow "frame within a frame" instead of solid
// (was a solid ring baffle_d deep, ~11.5mm wide around the whole
// perimeter -- most of that a slicer would fill as infill regardless
// of settings). Thin outer + inner walls connected by sparse ribs,
// with a thin solid cap at the front for a consistent visible
// bezel surface.
bezel_wall_t = 2.0;   // outer/inner wall thickness
bezel_cap_t = 1.5;    // solid front cap; rest of the depth is ribbed
bezel_rib_w = 3.0;    // rib width
bezel_rib_n = 4;      // ribs per straight edge (not counting corners)
// letter pixel size (letter = 5 x 7 pixels)
font_px = 1.1;
// face corner radius
corner_r = 3;
// per-side clearance for drop-in parts (lattice, diffuser) — FDM
// dimensional error + elephant-foot easily eats 0.2mm; this is
// clearance per EDGE, so the part shrinks by 2x this all round
fit_clr = 0.4;

/* [Body] */
// tray perimeter wall thickness
wall_t = 2.4;
// rear shell lid thickness
lid_t = 2.4;
// shell lip engagement depth
lip_h = 4;
// corner screw post outer diameter
post_d = 7;
// M3 self-tap pilot in the corner posts
post_hole_d = 2.7;
// radial clearance the shell's lip must keep from each corner post —
// the lip routes around the post rather than running through it, so
// this is a real per-edge allowance (not the ~0.4mm nominal gap the
// lip_out/wall_t formula implies, which the rsq() corner-rounding
// quirk eats into — see README fit note)
post_relief_clr = 1.0;
// support ribs for the corner posts: post height is wall_top-t_front,
// which grew substantially (17.4mm -> 27.4mm) when back_t increased
// for the depth-budget fix — a 7mm-diameter post that tall is a real
// snap risk, especially under screw-driving torque. Ribs connect each
// post to the tray wall in both X and Y. Kept clear of the shell's
// lip zone (the top lip_h of the post height, where the shell's lip
// registers and routes around the post — see shell()) by this much
// extra margin, so the ribs can't interfere with that routing.
post_rib_w = 3.5;     // rib width (tangential)
post_rib_clr = 2.0;   // margin below the lip zone
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

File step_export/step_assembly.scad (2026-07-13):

// Wrapper for STEP export via FreeCAD's importCSG: identical geometry,
// but vent_slot() is redefined without hull() (importCSG can't convert
// hull to BRep and would fall back to a mesh). A stadium is exactly a
// centred rectangle plus the two end circles, so this is equivalent.
include <../../wordclock.scad>

module vent_slot() {
    square([vent_slot_w, vent_slot_l - vent_slot_w], center = true);
    for (s = [-1, 1])
        translate([0, s * (vent_slot_l - vent_slot_w)/2]) circle(d = vent_slot_w);
}

// letters2d() without mirror() (also unconvertible) and without the
// ~20 overlapping pixel squares per glyph (OCC fails fusing all ~2400
// of them in the faceplate's single 2D difference). Each glyph is one
// precomputed outline polygon (letter_polys.scad, generated from
// font.scad at px=1.1 bleed=0.12 — exactly the union glyph2d() draws).
// The x-mirror is folded in by negating x coordinates:
// mirror(x) . translate([tx,ty]) == translate([-tx,ty]) . mirror(x).
include <letter_polys.scad>

module glyph_poly_flipped(ch) {
    hit = search([ch], LETTER_POLYS);
    if (ch != " " && hit != [] && hit[0] != [])
        for (lp = LETTER_POLYS[hit[0]][1])
            polygon([for (p = lp) [-p[0], p[1]]]);
}

module letters2d(n, grid) {
    for (r = [0:n-1], c = [0:n-1])
        translate([-(c - (n-1)/2) * pitch, ((n-1)/2 - r) * pitch])
            glyph_poly_flipped(grid[r][c]);
}

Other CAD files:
build/diffuser.stl
build/faceplate.stl
build/lattice.stl
build/shell.stl
build/stand_feet.stl

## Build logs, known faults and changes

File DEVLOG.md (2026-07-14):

# Development log — TIME INVADERS word clock

[README.md](README.md) covers what the project is and how to build
it; this file is the engineering history — bugs found, root causes,
fixes, and how each fix was verified. Sections appear in rough
chronological order; part names and parameters are as they were at
the time (the solid `stand`/`stand_sheet` discussed below were later
superseded by `stand_feet`/`stand_lowtail`, which inherited the same
profile work).

## ESP32 cradle & USB access — design evolution (v0.1.2–v0.1.5)

**v0.1.2 — ESP32 moved off the tray-wall corner to an internal cradle
above the pod** (`esp_x`/`esp_y`). Reasoning: routine USB access was
only ever needed for firmware flashing, and this design flashes once
on the bench pre-assembly, then updates OTA over WiFi from then on —
so there's no ongoing need for a side-wall port. This freed the corner
pad that used to be blocked by the cradle (see Ventilation below — all
4 corners are now uniform). **Trade-off, gone into with eyes open:**
if OTA ever bricks, recovery means opening the case and re-flashing
over USB on the bench, not a quick cable plug-in through the wall. The
old corner-cradle-against-the-wall design (and the faceplate's
matching tray-wall notch) is what earlier revisions of this doc
describe. **Faceplate reprinted** to drop the now-unused notch —
`build/faceplate.stl` is current (plain closed tray wall); an
already-printed faceplate from before this change still works fine
(the notch was always harmless, just unused), it just has the old
opening.

Long axis stays along X (`esp_l`) — matching the XIAO's long edges,
where its castellated pin pads actually are, same as the original
wall-mounted design (an earlier pass here rotated it 90° for no good
reason and got caught: nothing bounded the connector end, and it
landed 5.4mm from a pressure pad, not nearly enough room for a plug).
Retention is 4 small L-brackets, one per corner (`esp_corner_l`=2mm
along the long edge, `esp_tab_l`=3.5mm along the short edge, meeting
at the corner) — not full-length ribs. A 21×17.83mm FR4 board doesn't
need continuous edge support the way the 160mm flexible LED panel
does, so corner-only contact is plenty, and it sidesteps the whole
wire-exit-notch-position problem from the first two attempts at this:
the entire middle of both long edges (where the XIAO's actual pins
are — position unknown without the physical part in hand) and both
short edges (wherever the USB-C connector actually is) is just open.
The long-edge arm is deliberately short (2mm, just enough to locate
the board) rather than the 5mm first tried — it runs right alongside
the castellated pin row, so more reach only means more risk of
landing on a pad near the corner, for no retention benefit.
Nothing to guess, nothing to re-verify against real pin positions
later. Checked with `intersection()` against the pad grid, pod cavity,
vent rows, corner posts, and lip ring — all clear.

**Bug caught (v0.1.3):** `esp_clr` is documented as *per-edge*
clearance, but the channel-width formula only added it once across
the whole channel (`esp_w + esp_clr`) instead of once per edge
(`esp_w + 2*esp_clr`) — the board channel was 0.4mm tighter than
intended, on top of whatever an FDM print already eats (this project's
own fit-notes elsewhere show 0.2–0.4mm lost to that routinely). Fixed
both L-bracket arms to use `esp_w + 2*esp_clr`. Re-verified manifold
and re-ran all 5 `intersection()` checks (pad grid, pod, vents, posts,
lip ring) — still clear, the 0.4mm widening only ate into open space.

**v0.1.4 — universal footprint + less bulk.** Now that this feature is
a pure X/Y locator rather than a snug retention cradle (final
retention is the soldered leads + the foam/shell closing over
everything), it doesn't need to be sized to one specific board or
clear the USB-C connector's height. Checked a generic ESP32-S3
"supermini" against the XIAO: 22.52×18mm vs the XIAO's measured
21.12×17.83mm — widths agree to within 0.17mm, lengths differ by
1.4mm (supermini longer). Resized to `brd_w`=18/`brd_l`=22.52 (the
larger of each dimension) so either board locates the same way; the
shorter XIAO just gets ~1.4mm of lengthwise play, which doesn't matter
for a locator. `esp_l`/`esp_w` kept as reference (the XIAO's own
measurements), no longer wired into the cradle geometry.

Wall height dropped from `esp_usbc_h + 0.5` (≈5mm, sized to clear the
connector) to a flat `cradle_h` = 1.8mm (matches the rib-thickness
convention used elsewhere) — real bulk reduction. Deliberately **not**
done by cutting a recess into the 2.4mm lid itself: that would thin
the lid exactly where it needs to resist compressive load from the
foam pads pressing on it, trading bulk for a real strength risk.
Shortening material added *on top* of the lid instead leaves the
lid's own thickness untouched — same bulk win, no structural
trade-off. Re-verified manifold and re-ran all 5 `intersection()`
checks after the footprint grew ~1.4mm longer — still clear.

**v0.1.5 — 4 corners → 1 end-stop (`esp_stop_t`).** The v0.1.4
corner-bracket design had a real flaw: sizing the brackets to the
*union* of both boards' footprints meant the shorter XIAO wasn't
actually contained — it just had ~1.4mm of slop between end-stops
sized for the longer SuperMini, which isn't containment, it's a
rattle. A single rigid 4-corner cage can't snugly fit two different
lengths on both ends at once; there's no symmetric fix for that.

Resolved by not trying to contain both ends: a single straight wall
across ONE short edge only (`esp_stop_t` = 1.8mm thick, spanning
`brd_w + 2*esp_clr`), the other short edge and both long edges left
completely open. Both boards register against the same stop
regardless of length; the longer SuperMini's extra 1.4mm just extends
further into already-open space. Also lower pad-collision risk than
the old L-brackets: those touched a short-edge corner *and* reached
along the long edge (where most castellated pads run on both board
variants — pads come close to the board ends too, not just the long
edges, per physical inspection), whereas a single short-edge wall only
contacts the end face.

The geometry doesn't encode which end either board's USB-C connector
is on — genuinely can't, no verified pin/connector position data for
either board. **Assembly instruction, not a design assumption:**
insert the board with its connector facing the open end (away from
`esp_stop_t`), not the stopped end. Re-verified manifold and all 5
`intersection()` checks (pad grid, pod, vents, posts, lip ring) —
clear.

**Fit note (ESP32 board swap):** the cradle was originally sized from
a generic "ESP32-S3 supermini" guess and didn't fit any of three real
boards on hand (two supermini clones plus a Seeed XIAO ESP32S3).
Switched to the XIAO specifically — it's a tighter-toleranced, single-
vendor part. Re-measured with calipers rather than trusting a listing
(this project has been burned by that twice already): board 21.12 x
17.83mm, 1.15mm PCB, USB-C connector 4.49mm tall (tallest point,
measured from the underside of the board) and overhanging the board's
short edge by 1.49mm, centred on that edge, no mounting holes. Cross-
checked against third-party CAD bounding-box data (22.48 x 4.46 x
17.78mm including the connector overhang) — a close match, so these
are the numbers `esp_l`/`esp_w`/`esp_usbc_h` etc. are built from.
Retention is a friction-clip cradle since the XIAO has no mounting
holes, with a real `esp_clr` (0.4mm) clearance rather than folding
tolerance into the board-size variable. (Originally two full-length
ribs + a backstop wall; now 4 small corner L-brackets instead — see
Power & access for why.)

## Fit note: the lattice didn't fit the printed faceplate

**Fit note (v0.1.x reprint):** the first `lattice` export didn't
actually fit the printed faceplate. Root cause took two passes to
find — the frame's outer square (`ow`) was sized correctly, but the
per-cell crossbars are drawn independently at each LED-grid line, and
the outermost crossbar sits centred exactly on the grid edge
(`gs/2`), so its own width pushes it out to `gs/2 + lat_wall/2`
regardless of `ow`. That overshoot (161.2 mm total), not the frame,
was the part's real widest feature — so the first attempt to add
clearance by shrinking `ow` changed nothing measurable, because the
crossbars were never bounded by it. Fixed by clipping the whole
cross-section (frame + crossbars) to `ow` before extruding, so `ow`
is now genuinely the outer limit. Confirmed by measuring the actual
STL bounding box (160.2 mm, i.e. 0.4 mm/side against the fixed
161 mm opening), not just by reasoning about the code.
`fit_clr` (0.4 mm/side default) sizes `lattice`/`diffuser`/
`coupon_diffuser`; the lattice also shaves an extra 0.3 mm off the
outer frame for its first 0.6 mm (elephant-foot relief). This only
touches those three parts — **the faceplate's opening itself is
unchanged**, so an already-printed faceplate is still correct; just
reprint the lattice (and diffuser, if already printed).

## Fit note: shell rim vs. corner posts (the rsq() shrink bug)

**Fit note (shell rim vs. corner posts, and the real root cause):**
the shell's registration lip (a ring that seats inside the
faceplate's tray wall) ran into the four corner screw posts on test
fit. Root cause: the `rsq()` rounded-square helper's double
`offset(r) offset(-r)` silently shrank the *actual* shape by
`2×corner_r` beyond the size you passed it — confirmed against the
first-printed `faceplate.stl`, whose real bounding box was 178×178mm,
not the 184mm `face_w` the code implies. That ate most of the lip's
intended clearance against the posts, and shrank the post-to-tray-
wall corridor to ~0.6mm — too tight for the lip to route around the
posts at all without a sub-0.4mm-thick sliver of wall.

First attempt punched a plain circular hole through the lip at each
post — that cleared the interference (confirmed by rendering
`intersection()` of the faceplate and shell and checking it was
empty) but left an ugly break in the ring rather than routing around
the post. Decided against permanently living with either that
compromise or the tight corridor: **fixed `rsq()` itself** (drop the
redundant second `offset`, one line) and reprinted the faceplate at
its correct 184mm size instead of continuing to design around the
undersized one. That restores the corridor to ~2.6mm, which is
enough for the lip to route around each post as a real continuous
detour: the ring's inner edge locally bulges around a
`post_d + 2×post_relief_clr` circle at each post (`post_relief_clr`
= 1.0mm) instead of the outer boundary ever being touched. Verified
both ways — `intersection()` of faceplate and shell is empty
everywhere, and a 2D cross-section of the lip at each corner shows
one continuous band with a smooth circular notch, not a gap.
**Reprint both the faceplate and the shell** — the faceplate's actual
size changes (184mm, not 178mm), so the old one won't register with
the new shell correctly.

## v0.1.6 — depth-budget audit: this stack didn't actually fit its own contents

Caught late, after several rounds of shell-only rework: `foam_t` (now
`back_t`) and `panel_t` were both round numbers nobody had checked
against what actually has to physically live in them. Every check run
during the ventilation/pad-grid/cradle rework was a 2D XY-plane
`intersection()` — real and necessary, but it never once verified the
Z-axis (depth) against real component heights. Full audit, one pass,
covering everything rather than patching each part in isolation:

| Component | Old allowance | Real requirement | Fix |
|---|---|---|---|
| ESP32 XIAO (PCB→top of USB-C shell) | `foam_t` = 3.0mm | 4.49mm (measured, this project's own calipers) | Fit by `back_t` = 13mm |
| ESP32 SuperMini | 3.0mm | Unverified, no reason to expect shorter | Fit by `back_t` = 13mm |
| WS2812B panel (PCB + LEDs) | `panel_t` = 2.0mm | 1.8mm (measured: 0.25mm bare FPCB, 1.8mm total with LEDs) | Already fit — confirmed, not assumed |
| 1000µF capacitor | 3.0mm | 11.5mm minimum, any package (leaded or SMD — height doesn't change with mounting style) | Fit by `back_t` = 13mm (the tallest item — sets the whole budget) |
| Power socket | separate bump, own cavity (8mm) | 8mm (already correct — an earlier audit pass flagged this as broken based on a stale comment that was never reconciled with the real `pwr_cavity` value; retracted) | No change needed, relocated (see below) |
| Corner screw (M3×8) | 6.4mm clearance + 1.6mm engagement | ~6mm+ engagement for a reliable self-tap joint | M3×16 (~9.6mm engagement) |
| Panel lateral retention | none — bezel pocket was `baffle_d` deep only, panel sat in the much bigger tray opening beyond it | snug pocket matching the lattice/diffuser fit | Pocket extended through `panel_t` too |

**No bump-outs** — that was ruled out explicitly (a flat back was a
firm requirement), so instead of a local pocket for just the
capacitor, `back_t` grew to fit the *tallest* real component (the
cap) with margin, and everything else — the ESP32, the relocated
power socket — simply inherits that same headroom for free rather
than needing its own separate accommodation. `wall_top` and `slab_t`
both derive from `back_t` automatically, so this is one parameter
change cascading through the whole model, not a scattered patch.

**Power socket relocated, not just re-verified.** While auditing this,
reconsidered whether the socket should even stay as a separate bump-out
part at all: with real interior depth now available, it mounts
directly into the shell's own material instead — snap-fit flange
through the shell, cavity for wing deployment extending into the
(now roomy) interior. This removes the separate pod part *and* its
mounting screws entirely (retained purely by its own snap wings, same
mechanism as before) — one less part to print, and it means literally
every remaining screw on the assembled device is the same 4 corner
screws, all accessible from outside. **One number not re-verified
against the physical part:** the socket's flange now sits against the
shell's `lid_t` (2.4mm) rather than the old dedicated pod face
(2.0mm, the figure actually confirmed working) — 0.4mm thicker than
what was tested. **`part="pod_coupon"`** is a small standalone test
piece (40×40×10.4mm) of exactly this local geometry — flange cutout
through `lid_t`, cavity behind it — print that and check the real
socket snaps in properly before committing to a full shell print.

**Panel now has a real pocket.** The bezel ring used to extrude only
`baffle_d` deep, with its inner opening matching the lattice/diffuser
fit — but nothing beyond that depth constrained the panel at all; the
tray wall's own opening (179.2mm) is dramatically bigger than the
160mm panel, so it just sat loose. Extended the pocket depth to
`baffle_d + panel_t` so the same 0.5mm/side clearance the
lattice/diffuser already get now also captures the panel.

**Filament reduction, same pass.** That pocket wall used to be solid —
~11.5mm wide around the full perimeter, `baffle_d` deep, most of which
a slicer would fill as infill regardless of settings. Now that it's
even deeper (`baffle_d + panel_t`, capturing the panel too), rebuilt
it as a hollow "frame within a frame": thin outer + inner walls
(`bezel_wall_t` = 2mm) connected by sparse ribs (`bezel_rib_n` = 4 per
straight edge), with a thin solid cap (`bezel_cap_t` = 1.5mm) at the
front for a consistent visible bezel surface. Rough volume estimate:
~95cm³ solid → ~53cm³ hollow, **~44% less material** despite the
pocket being deeper than before. Checked with `intersection()` against
the corner posts (ribs sit in the same radial band, near the corners,
by design) — clear.

**Corner posts needed bracing.** Post height is `wall_top - t_front`,
which grew from 17.4mm to 27.4mm along with everything else in this
pass — a 7mm-diameter post that slender is a real snap risk, especially
under the torque of driving in the (now longer) M3×16 screws. Added
two ribs per post (`post_rib_w`), connecting each to the tray wall in
both X and Y. Kept clear of the shell's lip zone (the top `lip_h` of
the post, where the shell's lip registers and routes around the post)
by an explicit `post_rib_clr` = 2mm margin.

**Bug caught after the fact:** `rib_out` (how far each rib reaches
toward the tray wall) was computed as an absolute coordinate from the
faceplate's centre, then used as a local offset from the post's own
already-translated position — effectively adding `post_off` (~83.5mm)
twice, so the ribs shot ~81.6mm past the tray wall into open space.
The `intersection()` check against the lip zone didn't catch it: that
check only tests Z-separation from the lip's height band, which the
ribs satisfied regardless of how wrong their XY position was — it
verified the one thing that had been asked about without checking the
ribs' overall bounds against the faceplate outline at all. Fixed
(`rib_out` now correctly subtracts `post_off`) and re-checked two
ways: `intersection()` against the lip zone (empty, as before) *and*
`difference()` against the faceplate's own outer boundary — any rib
material left over after subtracting the full outline would mean it
pokes outside; empty, confirmed actually contained this time.

All of the above re-verified: manifold check on faceplate, shell, and
the full assembly, plus `intersection()` checks covering the new
pocket depth, the relocated socket mount, the post ribs against the
lip zone, and the existing pad grid/vents/cradle/lip ring/posts — all
clear.

## The stand never got updated for the new slab thickness

Missed entirely during the v0.1.6 depth-budget work — `groove_w`
(the stand's slot width, sized to the slab) is a formula
(`slab_t + groove_clr`) and scaled automatically when `slab_t` grew
21mm → 31mm. But the wedge it's cut *into* (`stand_depth`, `stand_h`,
the polygon in `stand()`) was all hardcoded and didn't move — so the
now-10mm-wider slot cut clean through the front lip, collapsing the
lip and support horn into a flat shell. Confirmed by rendering (image
inspection, not just the manifold flag — manifold only means
watertight, it doesn't mean "the slot stayed where it should").

First fix attempt (moving `groove_y` back to clear the lip) was
incomplete: it stopped the slot from touching the lip, but left only
**0.7mm** of material at the groove's lowest point — found by
computing the actual wedge-minus-slot cross-section as a point-sampled
2D region (`stand_depth`/`stand_h`/polygon vs. the slot cutter's real
transformed geometry), not by eyeballing a 3D render, which had
already produced one wrong "looks fine" read on this exact shape.
Raised the slot's Z-offset 4→8 (and the matching offset in
`assembly()`'s device positioning, 4.6→8.6 — the two have to move
together, there's no formula linking them) to get 4.69mm of margin at
that pinch point instead. Confirmed the fix with the same cross-section
method, plus a clean OpenSCAD `projection()` silhouette (a reliable
2D read, unlike the perspective renders that had already been
ambiguous twice on this shape) — lip, valley, and back wall all
present and solid.

Changed: `stand_depth` 92→104, horn position in the polygon 42/66→
60/84, `groove_y` 40→54 (now a shared top-level parameter — it used
to be a local variable in `stand()` *and* a separately hardcoded `40`
in `assembly()`, silently able to drift out of sync), slot Z-offset
4→8. Re-verified manifold on `stand()` and the full `assembly()`.

## Alternative stand: sheet-metal construction (`stand_sheet`, since superseded)

Optional, **not a replacement** for `stand()` — a second part, your
choice which to print. Same lip/horn/groove profile and angle as the
solid `stand()` (both now share `stand_profile_2d()`, so the sheet
version is guaranteed to hold the device at the same tilt — this
reuses the geometry that already took two rounds of fixing to get
right, rather than re-deriving the trig from scratch a third time),
but hollowed to a constant `sheet_t` (3mm) wall instead of solid —
genuine bent-sheet-metal construction, not a solid block that merely
looks thin. Extruded without end caps, so the open ends show the
material's cross-section, like a press-braked channel bracket viewed
end-on.

Real material saving, not just a different look: 49% less volume
than the solid wedge (179.2cm³ → 91.1cm³) — measured from the actual
exported meshes (signed-volume calculation over the STL triangles),
not estimated; an early draft of this note guessed 85% before
actually computing it.

Both `stand()` and `stand_sheet()` skip OpenSCAD's usual `Simple:`
manifold indicator in the CLI output — moving the groove cut into the
2D cross-section (shared by both) means there's no 3D CSG boolean at
the top level anymore, so OpenSCAD never invokes the CGAL check that
prints it. Verified watertightness a different way instead: exported
each STL and confirmed every mesh edge is shared by exactly 2
triangles (the standard watertight test), independent of what the
CLI chooses to report.

**Untested trade-off:** an open-ended channel is more prone to
racking/twisting under load than a solid wedge — 3D-printed PETG/PLA
has more inherent rigidity than real sheet steel even at this
thickness, but this hasn't been print-tested under the device's
actual weight. If it flexes more than expected, corner gussets or
closed end caps would be the next thing to try, not a reason to
distrust the base geometry (that part's shared with the
already-verified `stand()`).

## The pad grid never got updated for the new cavity depth either

Same root cause as the stand, caught by actually sweeping for it
afterward instead of waiting for it to surface part by part.
`pad_h` (1.0mm) was sized when the cavity behind the panel was 3mm
(`foam_t`): a short rigid nub plus the 3mm foam pad (BOM) together
just reached the panel, foam doing most of the bridging and providing
the actual clamping spring force. When `back_t` grew to 13mm for the
depth-budget fix, nobody revisited this — nub + foam only reached
4mm of the new 13mm gap, so the entire pad grid (added specifically
because a flexible PCB matrix sags at points the corner screws can't
reach) was clamping nothing.

Checked the other candidates that could have had the same problem
before assuming this was the only one: `cradle_h`/`esp_stop_t` (ESP32
locator wall) and `pwr_cavity[2]` (socket cavity) — neither was ever
meant to span the cavity, both are self-contained, both fine.
`pad_h` was the only dimension whose entire job was reaching across
the gap, and it's the one that broke.

Grown to 10.5mm — nub + the still-3mm foam (BOM unchanged) now
reaches 13.5mm against the 13mm gap, 0.5mm of deliberate interference
so the foam is under real compression rather than just touching, same
margin logic already used for the corner-post ribs. XY footprint is
unchanged, so the existing pad positions are still correct — only the
height changed. Re-verified manifold and re-ran all 5 `intersection()`
checks (vents, posts, lip ring, ESP32 cradle, socket mount) with the
taller pads — still clear.

## The stand's horn was sitting on top of the bottom vent row

Caught by inspection, not by me — the ventilation section below has
carried a "chimney effect, since the stand racks the face at a real
angle" claim since v0.1.1, but the stand's own horn geometry (the tall
support block the raked slab actually leans on, `Y=[60,84]` in the
stand's own frame, up to `stand_h`=34mm tall) was never checked against
where the vent slots land once the device is actually seated in it —
another instance of the same root cause as the stand/pad-grid misses
above: a change (or in this case, a design) evaluated in isolation
instead of against the full assembly.

Confirmed with a real measurement, not a re-eyeballed render (renders
of this exact junction had already been ambiguous once before, on the
groove fit): replicated the *identical* transform chain `assembly()`
applies to `device()` → `shell()` → the vent cut as an OpenSCAD
`function` (`vent_world_yz()`), placed marker spheres at the real vent
slot positions using it, exported both the stand and the markers to
STL, and checked containment with `trimesh`. Result: the bottom vent
row's exterior opening landed **0.19mm** clear of the horn's solid
material — inside the slicer's tolerance, i.e. functionally sealed, not
just tight. The top row was fine (>100mm standoff, nowhere near the
low stand). Checked whether `vent_y` alone could dodge it first: across
its entire achievable range the vent row's world position stays within
or right at the horn's footprint, so this wasn't a one-parameter fix.

Also worth noting for its own sake: the vent slot's full length (not
just its centre) matters here — after the tilt transform, a slot's
25mm long axis ends up spanning **21mm of world-Z** (nearly vertical),
not clustered near one point, so the fix below was sized against both
slot ends, not just the centre.

**Fix:** a relief notch cut straight into `stand_profile_2d()` (shared
by both `stand()` and `stand_sheet()`, so both get it automatically),
sized from the real vent geometry via `vent_world_yz()` rather than
hand-typed numbers — `vent_relief_y0/y1/z0/z1`, with 3mm margin added
on top of the measured slot extent. Because the whole stand extrudes
uniformly along `stand_w`, a single 2D notch in the cross-section opens
the full width automatically, reaching open air at both side edges of
the stand rather than needing 18 individual per-slot tunnels. The horn
keeps its full `Y=[60,68]` and `Y=[80,84]` depth solid on either side of
the notch, plus its full base below the notch — thinned locally where
the vents actually are, not hollowed out generally.

Re-verified with the same marker+`trimesh` method, this time sampling
both ends *and* the centre of every slot (108 points total, both rows):
worst-case clearance is now **3.0mm**, zero points inside solid
material. Stand volume dropped from 179.2cm³ to 164.2cm³ (~8% less,
consistent with a local notch, not a structural hollowing-out).

Also fixed in passing: `assembly()`'s device Z-offset (8.6) was still a
second hardcoded copy of the same number `stand_profile_2d()`'s own
groove fix depends on — flagged in that fix's own comment as a
future drift risk, and it was still separately typed in two places.
Hoisted to `device_z_off`, used by both.

**Untested trade-off:** the notch removes horn material at exactly the
point that takes the leaning slab's load. The remaining cross-section
looked reasonable in the render (base + both flanking Y-bands still
full height), but this is a CAD/geometry check, not a load test —
soak/flex-check the printed horn before trusting it holds the device's
weight unattended long-term, same caveat already standing for the
ventilation sizing itself below.

**Reprint required:** the stand only (today `stand_feet` or
`stand_lowtail`, which inherited this relief) — the device side of the
stack (faceplate/shell/lattice/diffuser/panel) is unaffected.

## Ventilation — full design history & sizing derivation (v0.1.1 — runs 24/7, so this isn't optional)

The original design pressed a **solid** 3 mm foam sheet against the
panel's full back face, sealed inside an otherwise-unvented shell —
fine mechanically, bad thermally. WS2812B panels dissipate real heat
(firmware caps sustained draw at 2.5 A/5 V = 12.5 W via
`setMaxPowerInVoltsAndMilliamps`), and running attract-mode content
unattended on a desk for hours had no way to shed that heat: sealed
PETG-GF shell, foam insulating the one surface that would otherwise
convect.

Fixed two ways, both in `shell()`:

- **Pressure ribs → pad grid.** The old ribs were already only 4 thin
  strips (not a full pad), so the real culprit was the *foam*, not the
  ribs — but a "#"-shaped pair of full-length strips still blocks two
  continuous bands across the whole back. Replaced with a sparse 3×3
  grid of 8×8 mm pads (`pad_off`/`pad_w`/`pad_h`), skipping the one
  point that lands in the pod cavity — 8 pads total. The lattice
  already supports the panel's front face at full 10 mm pitch, so the
  rear pads only need to take up stack tolerance, not hold the panel
  flat on their own. Foam gets cut to match: pads-worth of small
  squares, not a sheet — most of the back is now open air.

  **Corner pads:** the panel is a *flexible* PCB matrix, and the 3×3
  grid alone (reaching only ±`pad_off` = ±40) leaves the outer 40 mm
  of every edge — including all four corners at (±80,±80), the LED
  grid's actual extent — with zero clamping pressure, exactly where a
  flexible board sags most. Added pads at all 4 corners
  (±`corner_pad_off` = ±70 on both axes) reaching much closer to the
  corners, checked clear of the vent rows, corner posts, and lip ring.
  Uniform on all 4 now — an earlier pass here had the ESP32 cradle
  still parked in one of the corners, which cost that corner a full
  pad and needed a smaller special-cased one instead; moving the
  cradle to an internal position above the pod (see Power & access)
  freed it up, so this is simpler than it used to be, not more
  complex.

  **Edge-midpoint pads:** corners had dedicated support, but the
  left/right edge *midpoints* didn't — nearest pad was the inner
  grid's (±40, 0), 40mm from the true edge at ±80. Added (±`corner_pad_off`,
  0), reusing the same already-verified-clear X offset as the corner
  pads, cutting that to 10mm. 14 pads total now. Verified against a
  real physical concern, not just theory: checked the wire-exit
  positions from actual photos of the panel (three connector clusters
  along one edge) against the full pad grid, including these two —
  nearest pad-to-wire clearance is 17mm even along the tightest
  straight-line routing path, so the added pads don't crowd the
  wiring either. Manifold and all 5 `intersection()` checks (vents,
  posts, lip ring, ESP32 cradle, pod mount) re-verified with the
  larger grid — clear.

  Every pad in the grid — inner, corner, and these two — lands on an
  exact lattice wall intersection (walls at every 10mm: −80, −70, ...
  0, ... 70, 80; LEDs sit at the odd half-pitch positions in between,
  −75, −65, etc.), confirmed by checking pad coordinates against the
  actual wall positions computed from `lattice()`, not assumed from
  the round numbers looking plausible. Every pad presses on a rigid
  wall-to-wall crossing, never on open cell area or directly behind
  an LED.
- **Vent slots through the lid.** Two rows of 18 slots each, 3×25mm
  (`vent_slot_w/l/n`, `vent_span`, `vent_y`), positioned to clear the
  pad grid, the ESP32 cradle, the pod cutout, and the corner posts —
  checked with `intersection()` against each (all empty, OpenSCAD
  2021.01). Rows sit at the device's top and bottom edges (**shell y
  is mirrored vs the assembled device** — see the cradle comment in
  `shell()`) for a passive chimney effect, since the stand racks the
  face at a real angle: cool air in low, warm air out high, no fan.

  Sizing isn't a guess: the natural-convection stack-effect scaling
  A ≈ P / (ΔT^1.5 · √h), calibrated against the worked example in
  *Electronics Cooling*'s "A Practical Formula for Air-Cooled Boards
  in Ventilated Enclosures" (1997) — P′=10 W, ΔT=50°C, h=0.2m →
  643 mm²/vent — scaled to our h=0.136m (2×`vent_y`). Designed for
  P=10W (attract-mode-level sustained load, not just the ~3W word-
  display baseline) and ΔT=35°C, which calls for ~1300 mm²/row; 18
  slots at 3×25mm ≈ 1315 mm²/row. The original 9-slot pass (~291 mm²)
  only covered the best case (3W, 50°C rise) — undersized by 3–9×
  for realistic sustained load, hence the resize.

  This is still a rough lower bound, not CFD: the scaling omits the
  paper's own viscous flow-resistance term (real required area is
  probably somewhat *more* than this), and it's calibrated on a
  generic populated-board enclosure, not this specific flat-panel-
  near-vents geometry.

No filament swap needed — PETG-GF doesn't flex well enough for a
cantilever/spring-rib alternative anyway, and rigid ribs need the
foam's compressibility to take up tolerance regardless, so the pad
grid was the change, not the rib material.

**Not yet thermally validated** — the collision checks and the sizing
calc above are both just paper (well, CAD). Soak-test after reprinting
(attract mode, few hours, ambient desk conditions, check the panel/
ESP32 aren't running hot to the touch) before trusting this unattended
long-term; `vent_slot_n`/`vent_span` are easy to bump further if it's
still running warm.

**Reprint required:** `shell()` only — the stencil, diffuser, lattice,
and panel side of the stack are unchanged.

## README hero renders — lighting the face up (`face_display`)

The landing-page render originally showed the enclosure dark. Since
the letters are through-voids, "switching the clock on" in a render is
just dropping bright glyphs into the voids — `face_display` ("off" /
"time" / "invaders", in the [Part] Customizer tab) does exactly that,
reusing `letters2d`'s placement/mirror so the lit glyphs land in the
stencil voids, filled through the plate and 0.05 proud of the front
face. Preview-only: it draws inside `device()`, so no printable part
is affected. Word coordinates and the invader/cannon sprites are the
firmware's own tables (`grid.cpp` / `animations.cpp`, mirrored in
`docs/simulator.html`).

The committed renders (both 1400×1150, same camera so they read as a
pair):

```
openscad -o renders/assembly.png          --imgsize=1400,1150 \
  --camera=0,0,92,78,0,25,560 -D 'face_display="time"'     wordclock.scad
openscad -o renders/assembly_invaders.png --imgsize=1400,1150 \
  --camera=0,0,92,78,0,25,560 -D 'face_display="invaders"' wordclock.scad
```

`-o png` without `--render` uses the (fast, colour-capable) preview
renderer, which is what the colour() calls need anyway. The "time"
frame shows 4:23 — IT IS TWENTY THREE MINUTES PAST FOUR, the same
per-minute example the README leads with.

First cut of these renders let the background shine straight through
the unlit voids and out the back vents — assembly() doesn't model the
diffuser/panel drop-ins, so the stencil was open clean through, which
the built device never is. `device()` now also draws a near-black
`panel_blank_color` slab filling the panel opening behind the stencil
(preview-only, like the rest), so unlit letters read near-black the
way they do against the real (dark, unlit) diffuser stack.

The invaders frame then grew into an animated GIF for the README
(`renders/assembly_invaders.gif`): a hidden `anim_t` param (0–9)
ping-pongs the invader across the grid's five free columns while
alternating the two classic sprite poses (both from animations.cpp),
with the cannon drifting the opposite way; anim_t=2 reproduces the
static PNG exactly. All three README images now come from one script,
`./render_readme.sh` (10 frames + 2 stills, ~30 s each, then
ImageMagick). Two traps it works around: this machine's snap-confined
openscad can't write outside the repo, and ImageMagick's `-layers
Optimize` corrupted the global palette (cream background came out
lavender) — `-layers OptimizeFrame` optimizes without remapping.
Renders are byte-deterministic here, so a clean `git status` after
running the script doubles as a regression check.

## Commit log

2026-07-06 v0.1.0: parametric enclosure model — faceplate, shell, stand, coupon
    16x16 word clock, subtle desk-wedge concept. Stencil pixel font with
    bridged counters for letters-down printing with two colour swaps
    (dark/white/dark). All four parts validated manifold in OpenSCAD
    2021.01. Not yet test-printed.
    [font.scad, wordclock.scad]
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2026-07-06 Side USB-C access: ESP32 cradle moved to bottom corner
    The supermini's onboard USB-C now protrudes through a notch in the
    side tray wall (usb_side param picks left/right), giving flashing and
    power without opening the case. Shell lip and lid rim relieved for the
    plug overmold. Also fixes an orientation bug: the lid flips onto the
    tray (shell y mirrors), so the old pocket and cable exit actually sat
    at the TOP of the device — both now land at the bottom as intended.
    [wordclock.scad]
2026-07-06 Remove redundant rear cable exit — side USB-C is the only inlet
    [wordclock.scad]
2026-07-06 Per-minute word resolution — grid redesign
    IT IS TWENTY THREE MINUTES PAST FOUR, exact to the minute; corner
    minute pixels no longer needed. Fits 16x16 via letter-sharing
    (FOURTEEN>FOUR, TWONE=TWO+ONE, THREELEVEN, THREEIGHT, SEVENINE,
    PASTO, MINUTE<MINUTES). Keeps HIGH SCORE, INSERT COIN, SPACE
    INVADERS, GALAGA, DONKEY KONG, THE MATRIX, QBERT + stacked
    GAME/OVER; drops ASTEROIDS, FROGGER, PLAYER ONE.
    [wordclock.scad]
2026-07-06 Spacer between MINUTES and PAST (row 8: WAKA -> X + POW)
    MINUTES PAST is lit 48 min/hour, so it earns a real gap. POW stacks
    under ZAP and PAC in the last columns.
    [wordclock.scad]
2026-07-07 Row 15: THE MATRIX -> ASTEROIDS — hall of fame is pure 8-bit
    The Matrix rain animation stays as a selectable effect; only the
    hidden word goes. ASTEROIDS (also 9 letters) reclaims the slot it
    lost in the per-minute redesign.
    [wordclock.scad]
2026-07-07 Document power architecture: per-frame limiting + diode bypass
    Global brightness caps can't bound arbitrary animation frames
    (256 white @30% is still ~4.6A). FastLED per-frame power limiting
    is the firmware guarantee; VBUS diode bypass gives headroom to
    ~2-2.5A on a 5V/3A USB-C supply. BOM: 1000uF bulk cap + 330R data
    resistor added.
2026-07-07 Rear USB-C power breakout mount: separate feed for panel + ESP32
    Panel current never touches the dev board; the supermini's VBUS
    diode becomes source isolation so flashing while powered is safe.
    Slot + bosses parametric (pwr_*) — measure the actual breakout
    before printing the shell. Power budget raised to 2.5A.
    [wordclock.scad]
2026-07-07 Rear power pod replaces flat-breakout mount (which had a depth flaw)
    The slab interior is all panel+foam (~3.4mm free) — no socket body
    fits inside, and the previous corner mount would have collided with
    the foam. New: a small pod bump-out screwed to the back of the shell,
    bottom-middle above the stand horn, housing a pigtail USB-C power
    socket (Carl's PD-type pick). Parametric pwr_body/pwr_face_hole_d —
    measure the socket before printing. README: 5V-output warning for
    PD-trigger modules.
    [wordclock.scad]
2026-07-07 Pod reworked for the real snap-in socket (CHT-TS023R drawing)
    Carl supplied the engineering drawings: 4P PD pigtail variant, snap-in
    rectangular cutout 13.6x6.3 R1.3 in a 2.0mm face, cavity sized for
    body + snap-wing deployment, wires pass straight through into the
    enclosure. Replaces the guessed round nut-mount face. README: 2P
    variant warning (no CC = no VBUS on C-to-C), 5.1k CC termination note.
    [wordclock.scad]
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2026-07-07 Separate diffuser plate architecture (Carl's design improvement)
    No more filament swaps anywhere: faceplate becomes a plain dark
    stencil + tray, the diffuser is a drop-in sheet, the baffle lattice
    a drop-in grid (depth derives from t_diff). Diffuser is swappable
    after assembly and experimentable before it: the coupon gains a
    slide-in slot and coupon_diffuser test strips for A/B-ing
    thicknesses and materials (clear PETG now useful, not a mistake).
    Also kills the PLA/PETG interlayer bonding concern.
    [wordclock.scad]
2026-07-08 Fix lattice/diffuser fit: 0.2mm/side clearance was too tight for FDM
    The faceplate's opening (161mm) is fixed since it's already printed;
    lattice/diffuser were sized with only ~0.2-0.3mm/side clearance
    against it, not enough once dimensional error and elephant foot are
    accounted for on a 160mm span. New fit_clr param (0.4mm/side default)
    sizes both; lattice also gets elephant-foot relief on its outer
    frame's first 0.6mm. Faceplate itself is untouched -- only reprint
    lattice/diffuser/coupon_diffuser.
    [wordclock.scad]
2026-07-08 Actually fix the lattice overshoot (previous commit changed nothing)
    Carl measured the printed lattice at 161.20mm both before AND after
    the fit_clr change -- because the real widest feature was never the
    frame square (ow), it was the outermost per-cell crossbars, drawn
    independently at the LED-grid edge and overshooting to gs+lat_wall
    (161.2mm) regardless of ow. Shrinking ow was a no-op.
    Fix: clip the whole cross-section (frame + crossbars) to ow via
    intersection() before extruding. Verified by parsing the actual
    exported STL's bounding box (160.2mm), not just by re-reading the
    code -- the earlier commit message claimed a fix that a bbox check
    would have caught immediately.
    Co-Authored-By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
    [wordclock.scad]
2026-07-08 Pod: update to real socket dimensions (5.4x15.0mm cutout, 10mm total height)
    Measured off the actual delivered socket, superseding the earlier
    CHT-TS023R drawing estimate. Cutout 5.4x15.0mm R1.3 in a 2.0mm face;
    cavity resized to [10,18,8] to keep clearance around the new
    proportions; total pod height confirmed 10.0mm by measuring the
    exported STL bbox. Shell re-exported since its cutout/ear holes
    derive from the same pwr_cavity.
    [wordclock.scad]
2026-07-08 Fix pod cutout orientation: long axis now parallel to the ears
    pwr_snap_w/h and pwr_cavity w/h were swapped, so the cutout's long
    (15.0mm) dimension ran perpendicular to the two mounting lugs instead
    of parallel to them like the original part. Corrected both the snap
    cutout and cavity aspect so the long axis matches the ear-to-ear
    direction, confirmed visually and the 10.0mm total height held.
    [wordclock.scad]
2026-07-08 Add complete circuit schematic (ASCII, CaffePeso-style)
    Full wiring diagram: power pod (4P PD pigtail, CC pull-downs), the
    onboard-diode risk on the ESP32's own programming USB-C and how the
    firmware USB guard mitigates it, and the LED panel's power/data
    connections including the bulk cap and data resistor. Same layout
    convention as caffepeso/docs/USER_GUIDE.md's schematic -- boxed
    pins, sequential R/C designators, closing shared-rail notes, all in
    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
2026-07-08 Pod cutout: trim long side 0.3mm (15.0 -> 14.7mm) after test fit
    Confirmed by measuring the exported STL's cutout vertices directly:
    14.7 x 5.4mm (short side unchanged).
    [wordclock.scad]
2026-07-09 Fix rsq() corner-rounding bug, route shell lip around corner posts, refit ESP32 cradle for XIAO
    rsq()'s double offset() silently shrank every rounded part by 2x
    corner_r (faceplate printed at 178mm instead of the documented
    184mm). Fixed the helper and reprinted the faceplate at its correct
    size, which also gave enough clearance for the shell's registration
    lip to route around each corner post as a continuous band instead
    of punching a hole through it.
    Also swapped the ESP32 cradle from a generic "supermini" guess to a
    Seeed XIAO ESP32S3, measured with calipers after none of three real
    boards fit the old cradle. Flagged that the XIAO likely lacks the
    onboard VBUS diode the power architectur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
    [wordclock.scad]
2026-07-09 Add browser-based firmware simulator
    Ports grid.cpp/animations.cpp/display.cpp/webui.h to JS line-for-line:
    same word logic, all 6 transitions, all 6 attract shows, ambient
    Pac-Man, and the real mobile control UI, all driven off one shared
    simulated frame buffer. Useful for previewing wording/animations
    without hardware, and doubles as a live spec check against the
    firmware source.
2026-07-11 Shell rework: passive ventilation, sparse pressure-pad grid, ESP32 relocated internal
    Enclosure was fully sealed with a solid foam sheet insulating the panel's
    back — a real overheat risk for 24/7 desk use. Replaced the full-length
    pressure ribs with a sparse pad grid (incl. corner pads, since a flexible
    PCB matrix sags most at unsupported corners) and cut two rows of vent
    slots sized against a natural-convection stack-effect calculation, not a
    guess.
    Moved the ESP32 off the tray-wall corner to an internal cradle above the
    pod: routine USB access isn't needed (bench-flash once, OTA thereafter),
    which also freed a corner pad the old wall-mounted cradle used to block.
    The cradle itself went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
    [wordclock.scad]
2026-07-11 v0.1.6: fix depth budget, integrate power socket, repair stand
    Full audit after discovering the enclosure didn't actually fit its own
    electronics: the ESP32 (4.49mm) and a 1000uF cap (11.5mm minimum) both
    exceeded the 3mm cavity behind the panel. No bump-outs (explicit
    requirement) — grew back_t to 13mm instead, sized to the tallest real
    component, cascading through wall_top/slab_t (device thickness
    21mm -> 31mm).
    - Power socket now mounts directly into the shell (no separate pod
    part or screws — retained by its own snap wings)
    - Panel pocket extended through panel_t so the panel is actually
    captured by a snug wall instead of floating in the tray's much
    bigger opening
    - Bezel/pock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
    [coupon.stl, coupon_diffuser.stl, diffuser.stl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]
2026-07-11 Port the four new attract animations to the browser simulator
    Mirrors the firmware-branch additions (Asteroids, Galaga, Donkey
    Kong, Q*bert) into the JS-ported demo so the live simulator matches
    what's on the hardware — same sprites, colours, and per-word logic,
    plus buttons to trigger each one manually.
2026-07-13 Add wall-mount option and print-ready 3MF sets
    power_pos="bottom" and keyhole=true let the enclosure mount to a wall
    instead of the desk stand (connector through the tray's bottom edge,
    reinforced keyhole slot in the shell lid); both are unified behind a
    single mount_type="desk"|"wall" toggle so users don't need to hunt for
    the individual params. Verified against the shell's lip ring, corner
    posts, pressure pads, and vent slots (zero interference), and that
    mount_type="desk" reproduces the prior default geometry exactly.
    Also adds build/desk_set.3mf and build/wall_set.3mf: each is a single
    print-ready file containing all of that variant's parts as distinct
    objects (via the new pack_3mf.py,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
    [coupon.stl, desk_set.3mf, faceplate.stl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]
2026-07-13 Add STEP exports for all printable parts and the assembly
    Converted from the OpenSCAD model via FreeCAD with exact BRep geometry
    (analytic cylinders/planes; 2D profile arcs tessellated identically to
    the STL exports). wordclock_assembly.step contains faceplate, shell and
    stand_feet as separately named solids in their assembled positions;
    lattice and diffuser ship as individual files since assembly() does not
    place the drop-in parts.
    [diffuser.step, faceplate.step, lattice.step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]
2026-07-13 Add export_step.sh: reproducible OpenSCAD -> STEP pipeline
    FreeCAD's stock importCSG cannot convert this model (nulls out on 2D
    offset cuts, fused disjoint solids, tangent seams, mirror/hull), so the
    pipeline substitutes importable exact equivalents (step_export/
    step_assembly.scad wrapper + generated per-glyph letter outlines),
    pre-evaluates all 2D booleans with OpenSCAD's own exact engine
    (flatten2d.py), and rebuilds the tree as BRep solids in headless
    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
    [step_assembly.scad]
2026-07-13 Bring README up to date with the current model and build outputs
    - Printed-parts table: stand/stand_sheet -> the current stand_feet
    (default) and stand_lowtail; mark the older stand sections as
    historical where they present superseded parts as printable.
    - New "Ready-to-print & CAD files" section linking the committed
    build/ outputs (desk_set/wall_set 3MF, per-part STLs, STEP exports)
    and replacing the stale "STLs are not committed" claim.
    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
2026-07-13 Split the engineering history out of README into DEVLOG.md
    The README is the landing page — keep it to what the project is and
    how to build it. All bug/fix/verification narratives move verbatim to
    DEVLOG.md (ESP32 cradle evolution, lattice + shell-rim fit notes, the
    v0.1.6 depth-budget audit, both stand sagas, the pad-grid miss, the
    vent sizing derivation); Power & access and Ventilation get condensed
    current-state sections in their place, with cross-references updated.
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2026-07-14 Light the face up in the README renders (face_display toggle)
    New preview-only face_display param ("off"/"time"/"invaders") drops
    bright glyphs into the stencil voids so assembly renders show the
    clock switched on. Hero render now reads IT IS TWENTY THREE MINUTES
    PAST FOUR; a second render shows a Space Invaders attract frame.
    Word/sprite tables match the firmware. Render commands in DEVLOG.
    [wordclock.scad]
2026-07-14 Block see-through stencil voids in assembly renders
    The renders let the background show through unlit letters and out the
    back vents; the real device has the diffuser/panel stack there. Add a
    preview-only near-black panel blank behind the stencil in device() so
    unlit letters read dark, as built. Re-rendered both README images.
    [wordclock.scad]
2026-07-14 Animate the README attract render: Space Invaders march GIF
    Hidden anim_t param (0-9) ping-pongs the invader across the free
    columns alternating both classic sprite poses, cannon drifting the
    other way; anim_t=2 keeps the static PNG frame reproducible. New
    render_readme.sh regenerates all README images (stills + GIF; uses
    -layers OptimizeFrame — plain Optimize corrupts the palette). README
    now embeds the GIF in place of the static attract frame.
    [wordclock.scad]
2026-07-18 Rework Q*Bert and Asteroids attracts to use the whole face
    Asteroids: ship now spins at screen centre with 8-way procedural
    rotation; rocks drift in from the corners, get picked off by visible
    aimed shots and split into fragments that tumble away. Q*Bert: 6-level
    pyramid of 2x2 cubes spanning the face, zigzag hop path with mid-air
    frames, hop-off exit and a flash flourish on the changed cubes.
2026-07-19 Party theme, ghost boot, and retire the Matrix rain
    - New Party theme: every lit letter gets its own colour (golden-angle
    hue per cell, slow drift) via timeCellColor(), which all transitions
    now use so the multicolour survives fades and drops.
    - Boot now summons a big Pac-Man ghost that flickers frightened-blue
    before the time fades in, replacing the Matrix rain intro.
    - Matrix rain removed: animation deleted, dropdown option and attract
    button gone; enum slots kept so stored configs keep their meaning,
    random pickers skip the dead slot.
2026-09-29 README: mark web OTA as unproven; update over USB for now
    The only OTA use sent a build that turned out to be broken, so OTA was
    never confirmed working, and the finished clock has no external port.
    Say so instead of promising OTA after assembly.
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2026-09-30 Simulator: Replay boot no longer fights the running loop
    restartClock() ran animBoot alongside tick(), so boot frames and the
    normal face interleaved, and it zeroed the attract/hidden-word timers,
    firing both straight after. Boot is now a queued request handled by
    tick(), with fresh timers and the current minute marked as shown, the
    same as the firmware at power-on.
